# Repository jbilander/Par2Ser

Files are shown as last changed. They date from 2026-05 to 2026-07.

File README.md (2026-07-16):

# Amiga Par2Ser device

> 🚧 **Status: Proof of concept — working, not yet fast.** The link is
> verified end-to-end on real Rev 2A hardware in both directions: interactive
> terminal traffic and **kermit file transfers** both work (a 512 KB ROM image
> and a 906 KB binary have been transferred with essentially zero packet
> errors). Current throughput is roughly **3400 CPS transmit / 1400 CPS
> receive** (release build). That is not yet a win over the built-in serial
> port — a stock A500 runs kermit at 38400 baud (~3800 CPS) via `8n1.device` —
> so **throughput optimization is the active work**; the whole point of going
> through the parallel port is to beat that comfortably. There are no tagged
> releases until it does, so **build at your own risk** and expect the design
> to still change. PRs and issues welcome.

***
Rev. 2A <br />
<a href="images/Par2Ser_rev2A_pic1.png">
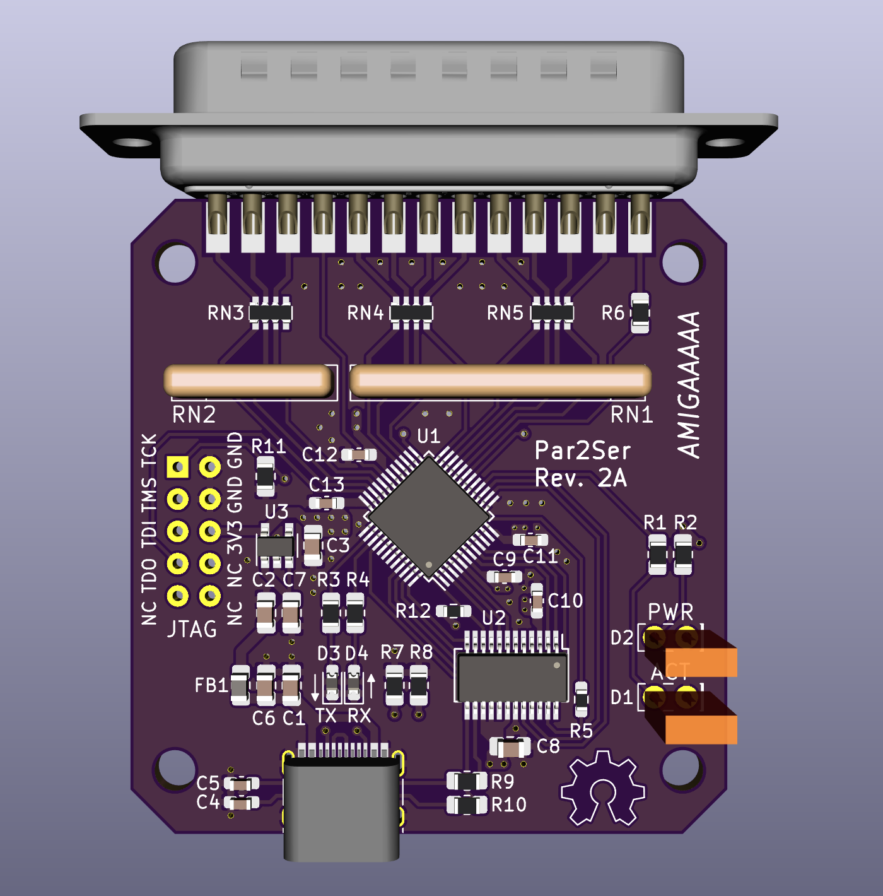
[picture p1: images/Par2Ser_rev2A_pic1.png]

</a>

***

A `serial.device`-compatible Amiga driver that bridges the parallel port to a
USB FIFO (FT240X) via Niklas Ekström's 2E parallel-adapter protocol, so unmodified
comms programs (c-kermit, NComm, …) can `set line par2ser.device`.

The hardware side is a small board built around a Lattice **LC4064V-75TN48C**
CPLD that speaks the 2E protocol to the Amiga and presents the bytes to an
**FT240X** USB FIFO. The PC sees a standard USB serial port (VCP).

## Repository layout

- **`amiga/`** — `par2ser.device` driver source (m68k, Bartman gcc).
- **`cpld/`** — Verilog firmware for the Lattice LC4064V CPLD.
  - `rtl/` — design sources (`par2ser_top.v`, `par2ser_fsm.v`).
  - `sim/` — Icarus Verilog smoke testbench.
  - `isplever/` — Lattice ispLEVER Classic 2.1 project files and pin
    constraints (`Par2Ser.lci`).
- **`KiCad/`** — KiCad 5.1 schematic and PCB sources (Rev 2A).
- **`FT_PROG/`** — FT_PROG template (`Par2Ser.xml`) capturing the
  FT240X MTP settings the bridge needs (VCP enabled, CBUS5 → CLK12MHz,
  product description). Open it in FT_PROG and apply to a fresh
  board to skip the manual click-through.
- **`images/`** — board photos and screenshots used in this README.
- **`Par2Ser_rev2a_schematic.pdf`** — exported schematic for quick
  reference without opening KiCad.

## Hardware overview (Rev 2A)

- **Lattice LC4064V-75TN48C** CPLD (48-pin TQFP, 64 macrocells, -75 speed)
- **FTDI FT240X** USB-to-parallel-FIFO (SSOP-24), USB-C connector
- **8-bit bidirectional buffer** between the Amiga DB-25 and the CPLD
- **JTAG header** for programming the CPLD via ispVM System with a
  cheap FT4232H-mini-module-based cable

The driver is built in the style of [SimpleDevice](https://github.com/jbilander/SimpleDevice)
for the Bartman `m68k-amiga-elf` (gcc 15.1) toolchain. The serial machinery
(receive ring buffer, `CMD_READ` satisfied from buffer, `SDCMD_QUERY` count
from a software counter) is ported from Iain Barclay's `8n1.device` 43.5.

It targets **Kickstart 1.3** (and up): the sources include `<ks13_compat.h>`,
which uses `#pragma GCC poison` to turn any accidental call to a KS 2.0+
library function into a compile error, so the driver stays loadable on an
unexpanded A500/A2000.

## Bill of Materials (Rev 2A)

Sourcing notes: most actives and precision passives are from
[Mouser](https://www.mouser.com/), the connectors and decorative
LEDs are inexpensive enough to come from AliExpress sellers (linked
examples below — any equivalent footprint works). Generic 0805/0603
passives can be substituted with any reputable manufacturer's part
matching the value, package, and dielectric/tolerance noted.

| Ref | Qty | Value / Part | Description | Package | Source | Notes |
|---|-----|---|---|---|---|---|
| **U1** | 1 | LC4064V-75TN48C | Lattice ispMACH 4000V CPLD | 48-TQFP | [Mouser 842-LC4064V75TN48C](https://www.mouser.com/ProductDetail/842-LC4064V75TN48C) | 64 macrocells, -75 speed grade |
| **U2** | 1 | FT240XS-R | FTDI USB-to-parallel FIFO | SSOP-24 | [Mouser 895-FT240XS-R](https://www.mouser.com/ProductDetail/895-FT240XS-R) | USB 2.0 Full Speed; VCP driver |
| **U3** | 1 | TLV75533PDBVR | TI 3.3 V LDO regulator, 500 mA | SOT-23-5 | [Mouser 595-TLV75533PDBVR](https://www.mouser.com/ProductDetail/595-TLV75533PDBVR) | Fixed 3.3 V output |
| **J1** | 1 | DB25 Male | Right-angle PCB DB-25 (M) | Solder cups | [AliExpress example](https://www.aliexpress.com/item/1005006354086316.html) | Amiga parallel port |
| **J2** | 1 | USB-C 2.0 (TYPE-C-02) | 16-pin USB-C, USB 2.0 only (no SuperSpeed) | SMD + THM tabs | [AliExpress example](https://www.aliexpress.com/item/1005005371954812.html) | Common "TYPE-C-02" footprint |
| **J3** | 1 | 2×5 pin header | 2.54 mm pitch, 10-pin (2×5) | Through-hole | [AliExpress example](https://www.aliexpress.com/item/1005001493183557.html) | Optional — can press-fit ribbon during programming |
| **FB1** | 1 | 600 Ω @ 100 MHz | Ferrite bead | 0805 | [Mouser 875-HZ0805E601R-10](https://www.mouser.com/ProductDetail/875-HZ0805E601R-10) | USB VBUS filter |
| **D1** | 1 | Yellow LED | Activity LED (optional) | 2×5×7 mm TH | [AliExpress example](https://www.aliexpress.com/item/1005006220921860.html) | Lit when transaction in progress |
| **D2** | 1 | Green LED | Power LED (optional) | 2×5×7 mm TH | [AliExpress example](https://www.aliexpress.com/item/1005006220921860.html) | 3.3 V rail indicator |
| **D3** | 1 | Red LED | TX LED | 0603 SMD | [AliExpress example](https://www.aliexpress.com/item/1005005975741298.html) | Amiga → PC byte flow |
| **D4** | 1 | Red LED | RX LED | 0603 SMD | [AliExpress example](https://www.aliexpress.com/item/1005005975741298.html) | PC → Amiga byte flow |
| **RN1** | 1 | 8×10 kΩ bussed (A09-103JP) | 9-pin SIP resistor network | SIP-9 | [AliExpress example](https://www.aliexpress.com/item/1005006954621214.html) | Amiga D0..D7 pull-ups, one common |
| **RN2** | 1 | 4×10 kΩ bussed (A05-103JP) | 5-pin SIP resistor network | SIP-5 | [AliExpress example](https://www.aliexpress.com/item/1005006954621214.html) | Additional Amiga-side pull-ups |
| **RN3, RN4, RN5** | 3 | 4×330 Ω isolated | 8-pin SMD isolated resistor array | 1206-8 | [Mouser 652-CAY16-3300F4LF](https://www.mouser.com/ProductDetail/652-CAY16-3300F4LF) | Series limiters on signal lines |
| **R1, R3, R4** | 3 | 1 kΩ | LED current limiter / signal | 0805 | [Mouser 652-CR0805FX-1001ELF](https://www.mouser.com/ProductDetail/652-CR0805FX-1001ELF) | |
| **R2** | 1 | 10 kΩ | Series for D2 power LED (high R = low brightness) | 0805 | [Mouser 652-CR0805FX-1002ELF](https://www.mouser.com/ProductDetail/652-CR0805FX-1002ELF) | Matches green power-LED forward voltage |
| **R5** | 1 | 33 Ω | CLKOUT line damping resistor | 0603 | [Mouser 652-CR0603FX-33R0ELF](https://www.mouser.com/ProductDetail/652-CR0603FX-33R0ELF) | Common practice for clock lines, not per FT240X datasheet  |
| **R6** | 0 | 330 Ω (**DNP**) | Series on /STROBE — not populated | 0805 | [Mouser 652-CR0805FX-3300ELF](https://www.mouser.com/ProductDetail/652-CR0805FX-3300ELF) | **Do Not Place** — populate only if /STROBE used in fw |
| **R7, R8** | 2 | 5.1 kΩ | USB-C CC1/CC2 pull-downs | 0805 | [Mouser 652-CR0805FX-5101ELF](https://www.mouser.com/ProductDetail/652-CR0805FX-5101ELF) | Identifies device as USB 2.0 (sink) |
| **R9, R10** | 2 | 27 Ω | USB D+/D− series | 0805 | [Mouser 652-CR0805FX-27R0ELF](https://www.mouser.com/ProductDetail/652-CR0805FX-27R0ELF) | Per USB 2.0 Full Speed spec |
| **R11** | 1 | 4.7 kΩ | Pull-down for TCK (JTAG) | 0805 | [Mouser 652-CR0805FX-4701ELF](https://www.mouser.com/ProductDetail/652-CR0805FX-4701ELF) | Standard JTAG practice |
| **R12** | 1 | 10 kΩ | Pull-up for SIWU# | 0603 | [Mouser 652-CR0603-JW-103ELF](https://www.mouser.com/ProductDetail/652-CR0603-JW-103ELF) | Keeps SIWU# deasserted when CPLD pin 44 is high-Z |
| **C1, C2** | 2 | 4.7 µF, 10 V, X7R | VBUS bulk / LDO input | 0805 | [Mouser 81-GRM21BR71A475KE1K](https://www.mouser.com/ProductDetail/81-GRM21BR71A475KE1K) | Murata GRM21 X7R, 10 V |
| **C3** | 1 | 1 µF, X7R | LDO output filter | 0805 | | Per TLV75533 datasheet |
| **C4, C5** | 2 | 47 pF, C0G/NP0 | USB D+/D− noise filter | 0603 | [Mouser 791-0603N470G160CT](https://www.mouser.com/ProductDetail/791-0603N470G160CT) | Tight tolerance important |
| **C6, C7, C8** | 3 | 0.1 µF, X7R | Decoupling (0805 spots) | 0805 | | |
| **C9 – C13** | 5 | 0.1 µF, X7R | Decoupling (0603 spots) | 0603 | | One per VCC pin |

**Distinct line items: 27** &nbsp;·&nbsp; **Components to populate: 37** (38 if /STROBE is wired up in a future firmware — see R6)

### Mounting and additional hardware

- The **LC4064V** is JTAG-programmable in-circuit — no socket needed.
- The **JTAG header (J3)** uses the standard Lattice 2×5 pinout —
  check `cpld/README.md` for the exact pinout and the recommended
  FT4232H-Mini-Module-based cable. The header doesn't have to be
  soldered down; you can press-and-hold the 2×5 ribbon cable
  against the pads during programming.

### 3D-printable case

A 3D-printable two-part case is provided in the `3D/` folder. It is
adapted from the former **SDBox-v2** case, slimmed down and made more
proportional — the Rev 2A design no longer has to house a bulky
Arduino Nano v3, so the enclosure is significantly thinner. The DB-25
exits one end and the USB-C port the other, and the top lid has two
holes for the panel LEDs: one for the **Power LED (green)** and one for
the **Activity LED (yellow)**.

| File | Description |
|---|---|
| `3D/Par2Ser.scdoc` | SpaceClaim source file for the case |
| `3D/Par2Ser.stp` | STEP export (top + bottom) for use in other CAD tools |
| `3D/Par2Ser_top.stl` | Top lid, ready to slice and print |
| `3D/Par2Ser_bottom.stl` | Bottom shell, ready to slice and print |
| `3D/Par2Ser_text.skp` | SketchUp source for the embossed "Par2Ser" lid text |

<table>
  <tr>
    <td align="center">
      <a href="images/Par2Ser_case_pic3.png">
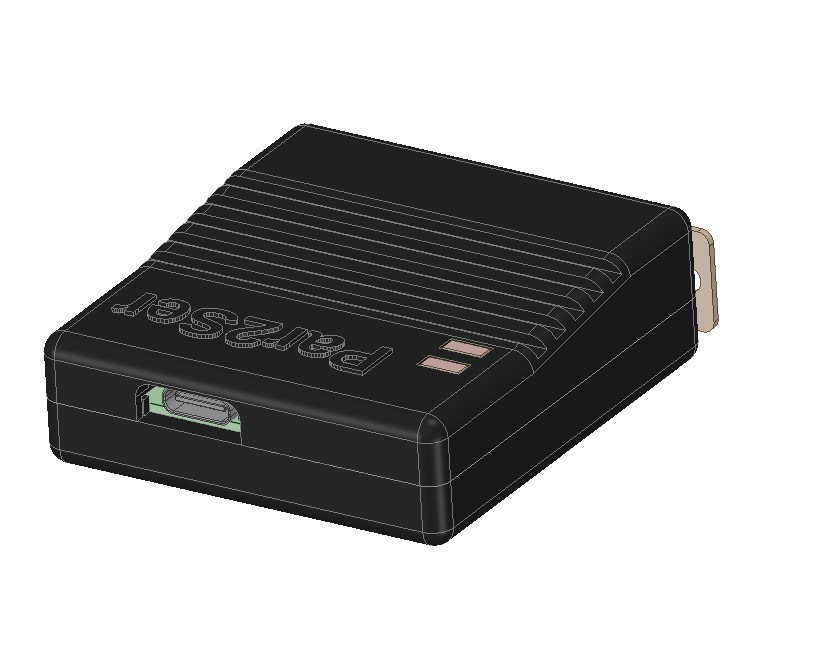
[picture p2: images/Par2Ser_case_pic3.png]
        
      </a><br />
      <sub>USB-C end, with the two LED holes in the top lid</sub>
    </td>
    <td align="center">
      <a href="images/Par2Ser_case_pic1.png">
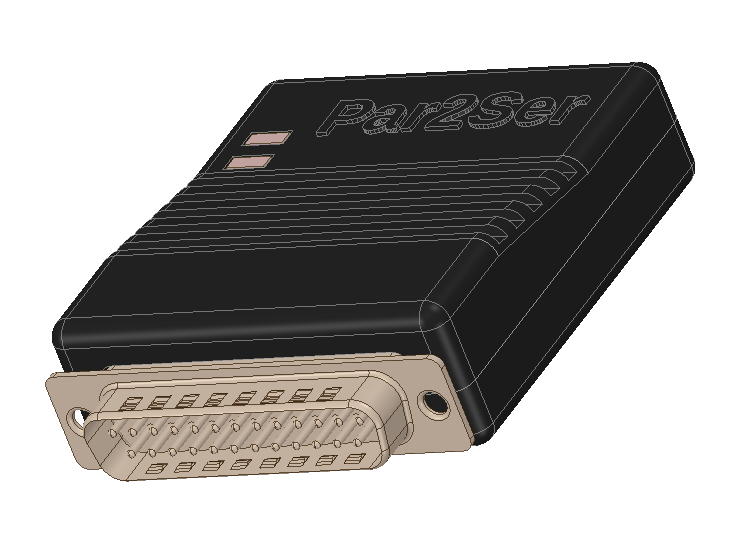
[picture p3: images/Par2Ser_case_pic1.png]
        
      </a><br />
      <sub>DB-25 end</sub>
    </td>
  </tr>
  <tr>
    <td align="center">
      <a href="images/Par2Ser_case_pic4.png">
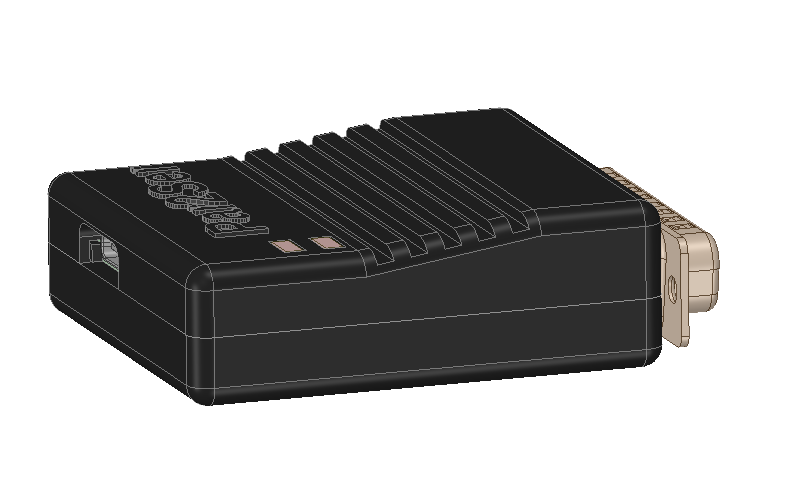
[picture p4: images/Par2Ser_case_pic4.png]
        
      </a><br />
      <sub>Side profile showing the slimmer enclosure</sub>
    </td>
    <td align="center">
      <a href="images/Par2Ser_case_pic2.png">
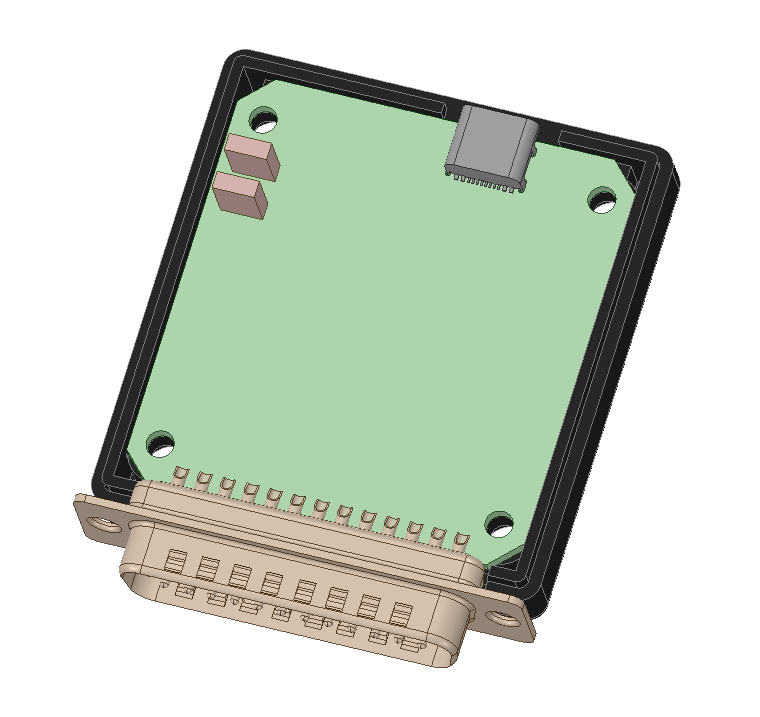
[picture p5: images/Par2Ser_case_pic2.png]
        
      </a><br />
      <sub>PCB fitted into the bottom shell</sub>
    </td>
  </tr>
</table>

The renders above are from the CAD program. The case was printed on a
Creality Ender-3 Pro in white PLA. The build photos below show the
assembly steps and the finished unit fitted to an Amiga 500.

#### Fitting the panel LEDs

The two indicator LEDs are soldered last. Fit the **PWR (green, Power)**
and **ACT (yellow, Activity)** LEDs into their positions, then check
from the top that each one protrudes ever so slightly through its hole
in the case lid. Once the height looks right, tack down a single leg,
snip the leads flush, and only then solder both joints properly. Doing
it in that order keeps the LEDs sitting at the correct height instead of
being pushed in or standing too proud.

<table>
  <tr>
    <td align="center">
      <a href="images/Par2Ser_soldering_PWR_and_ACT_LEDs.jpg">
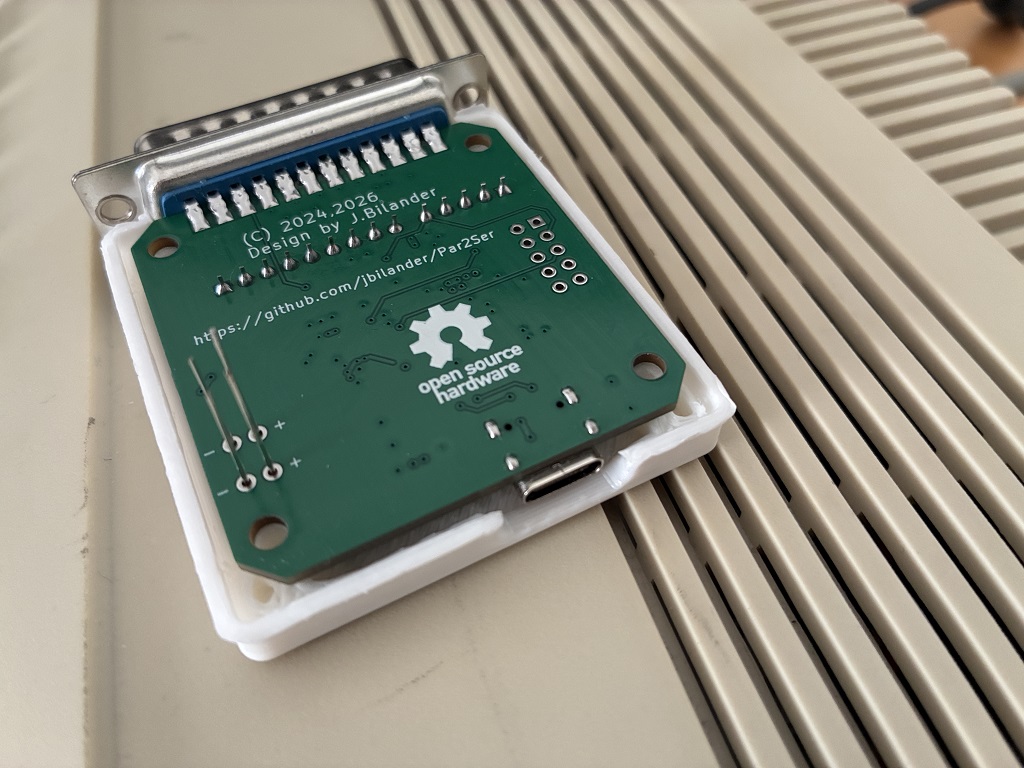
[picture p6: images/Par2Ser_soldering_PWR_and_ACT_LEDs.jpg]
        
      </a><br />
      <sub>Test-fitting the green PWR and yellow ACT LEDs before tacking them down</sub>
    </td>
    <td align="center">
      <a href="images/Par2Ser_soldering_completed.jpg">
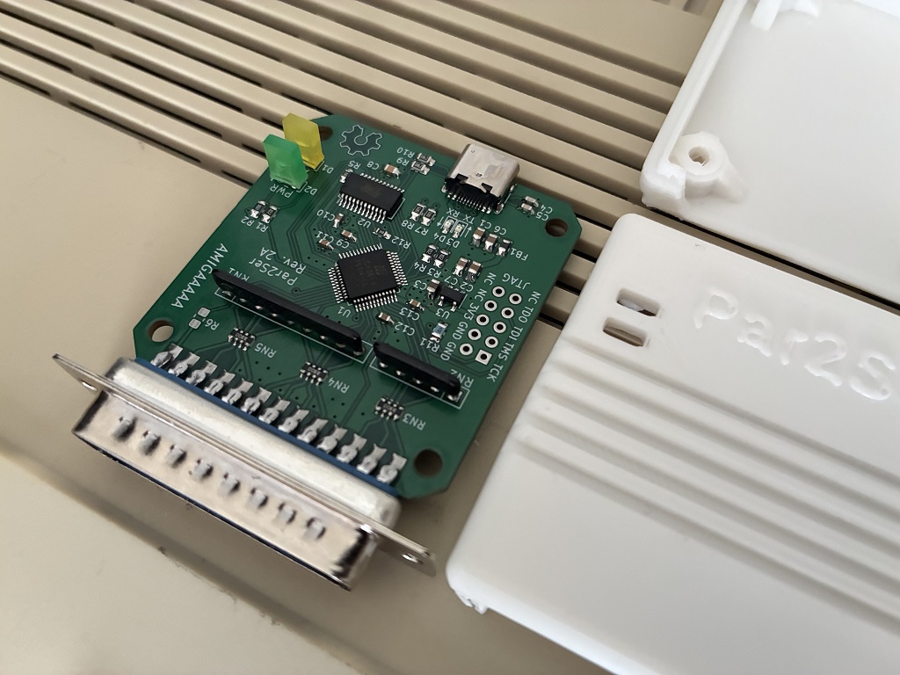
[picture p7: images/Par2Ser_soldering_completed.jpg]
        
      </a><br />
      <sub>Underside of the finished board seated in the bottom shell</sub>
    </td>
  </tr>
</table>

#### Finished unit

<table>
  <tr>
    <td align="center">
      <a href="images/Par2Ser_installed_in_case.jpg">
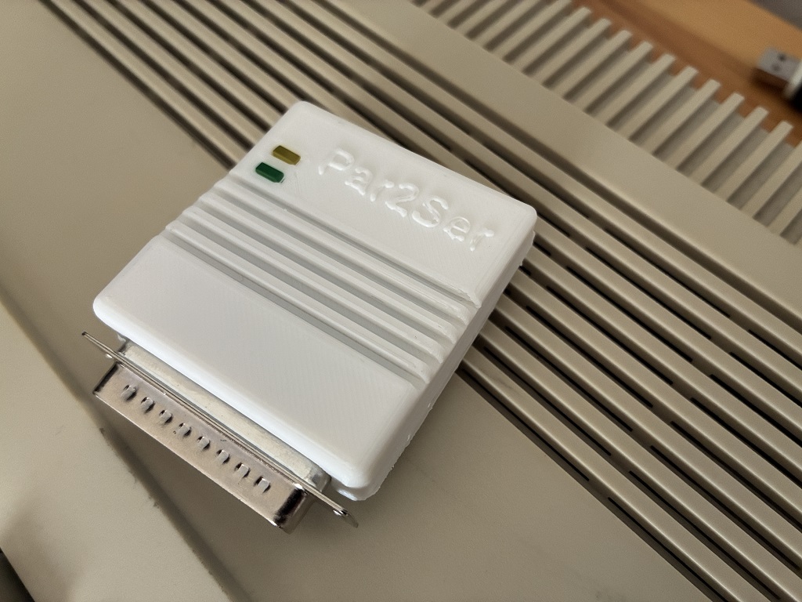
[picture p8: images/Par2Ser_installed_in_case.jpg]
        
      </a><br />
      <sub>Assembled case closed up, with the PWR/ACT LEDs visible through the lid</sub>
    </td>
    <td align="center">
      <a href="images/Par2Ser_installed_in_A500_and_connected_to_PC.jpg">
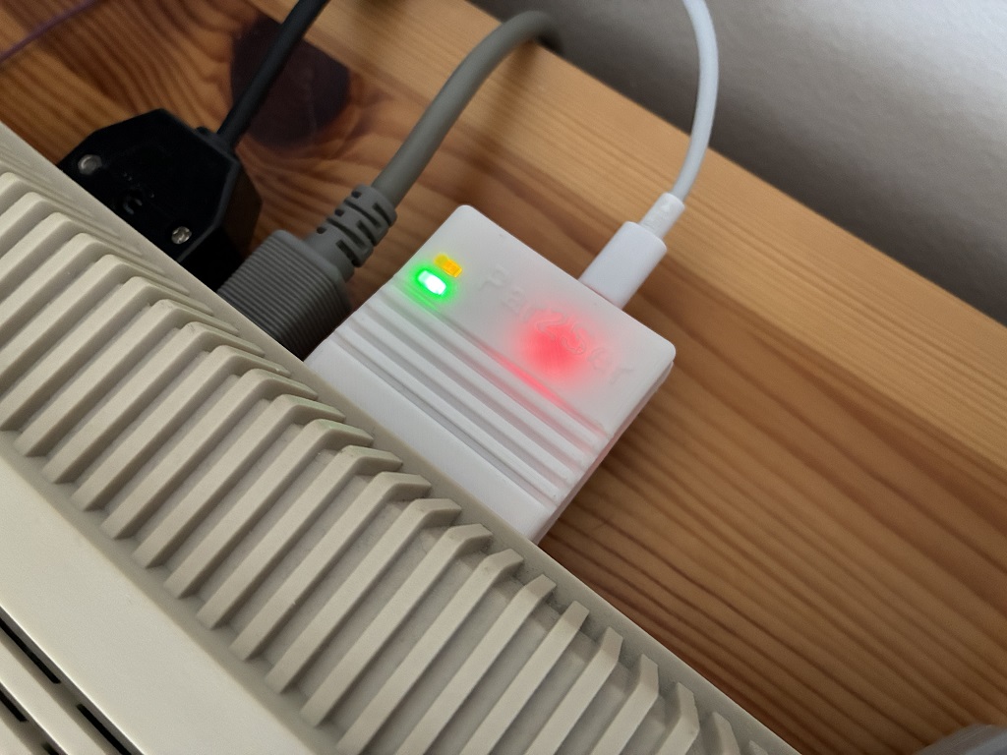
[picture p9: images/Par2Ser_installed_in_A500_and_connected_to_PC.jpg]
        
      </a><br />
      <sub>Plugged into the A500 parallel port and connected to a PC over USB-C</sub>
    </td>
  </tr>
</table>

In the powered-on photo the green **PWR** LED is lit, and the red glow
bleeding through the lid is the FT240XS **RX/TX** LEDs shining through
the white PLA — here the blink firmware has the **TX** LED on. This is
something of a happy accident: if you don't want the glow, print the
case in black or another dark material, or simply leave the RX/TX LEDs
unpopulated.

> **Note:** The USB-C cut-out in the current print is slightly too wide.
> It's a cosmetic issue only — the port works fine — and will be tidied
> up shortly so the opening sits more symmetrically around the connector.

## Files (amiga/)

- `par2ser.c` — device skeleton + serial command set + receive ring buffer
- `transport.h` / `transport.c` — byte-pipe to the adapter (**stubbed** for now)
- `debug.c` — `KPrintF` over `RawDoFmt`/`RawPutChar` (verbatim from SimpleDevice)
- `Makefile`

## Build (amiga/)

```sh
cd amiga
make debug      # build-debug/par2ser.device, with KPrintF tracing
make release    # build-release/par2ser.device, stripped
```

Adjust `INCDIRS` for your NDK path as in SimpleDevice.

## Programming the FT240X (one-time, before first use)

The CPLD needs a 12 MHz clock from the FT240X to operate. By default
the FT240X's CBUS5 pin is **not** configured as a clock output — you
have to set its function in the chip's internal MTP (one-time-programmable)
memory using FTDI's **FT_PROG** utility. While you're at it, you should
also tell the chip to advertise itself as a Virtual COM Port (VCP) so
that comms software on the host can open it as a regular serial port,
and you can optionally set a friendly USB product-description string.

These settings are all stored on the FT240X chip itself — they
persist across power cycles and across host machines.

### What you'll need

- FTDI **FT_PROG** (free download from <https://ftdichip.com/utilities/>;
  requires .NET Framework 4.0 or newer, which is included with
  Windows 8.1 and above)
- The Rev 2A board, powered via USB, on a Windows machine (FT_PROG
  is Windows-only; users on Linux/macOS can use a Windows VM, or
  the open-source `ftdi_eeprom` from libftdi as an alternative —
  see note at the end of this section)

### Install FT_PROG

Download FT_PROG from <https://ftdichip.com/utilities/> (current version
at time of writing: 3.12.75.692). Extract the ZIP, run the installer,
click through to **Finish**:

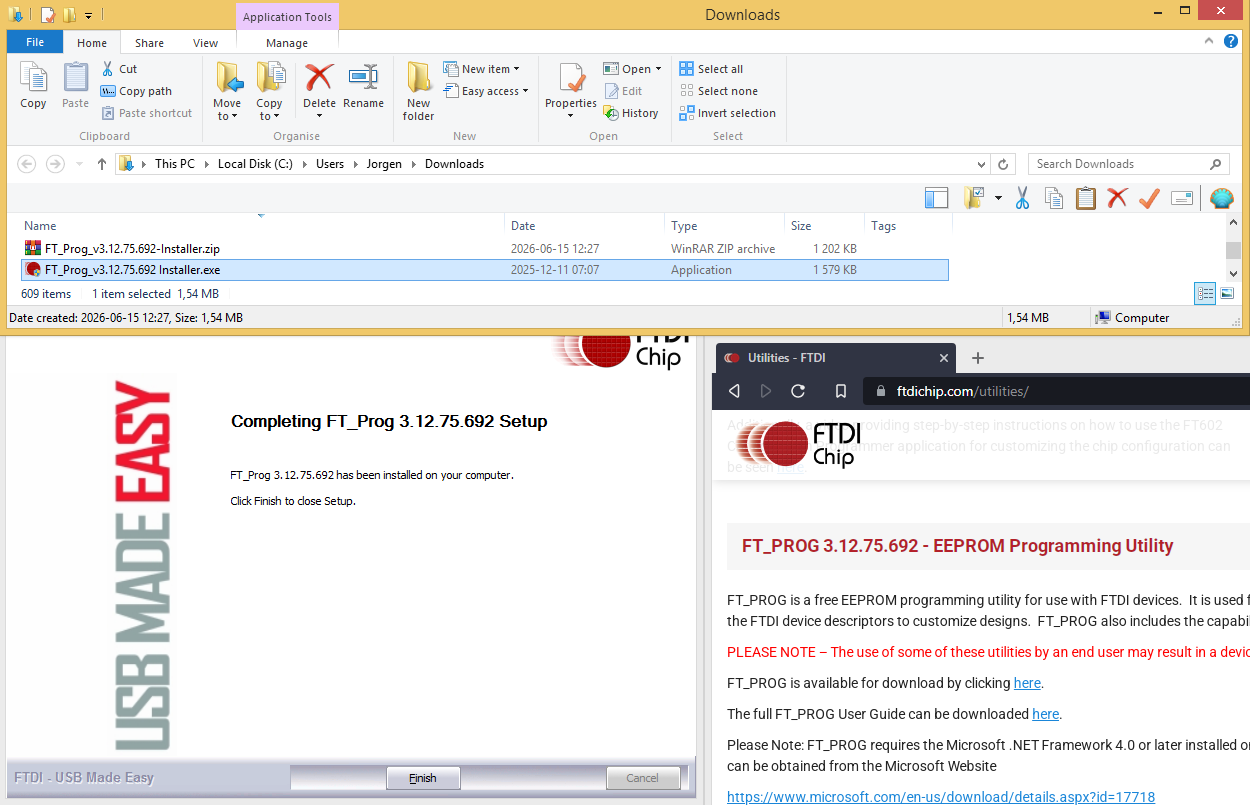
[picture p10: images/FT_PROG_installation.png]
FT_PROG installer


### Fast path: apply the supplied template

The `FT_PROG/Par2Ser.xml` file in this repo is a saved FT_PROG template
with all the settings the Par2Ser bridge needs (VCP enabled, CBUS5 →
CLK12MHz, CBUS6 → Keep_Awake#, Product Description → `Par2Ser USB Serial`).
The fast path is:

1. Plug the Rev 2A board into a Windows PC via USB-C. Windows will
   detect the FT240X and bind FTDI's bus-level driver, presenting
   the device as **"USB Serial Converter"** under
   *Universal Serial Bus controllers* in Device Manager.
2. Launch FT_PROG and **FILE → Open** the `FT_PROG/Par2Ser.xml`
   template — this loads the desired settings into FT_PROG's editor.
3. **DEVICES → Scan and Parse** (<kbd>Ctrl+P</kbd>) to bring the
   live chip's current settings under the same editor.
4. **DEVICES → Program** to apply the template values to the chip
   — confirm the success dialog appears.
5. Unplug and replug the board.

If you'd rather understand or customize each setting, walk through
the manual steps below instead.

### Manual walkthrough (step-by-step)

1. Plug the Rev 2A board into a Windows PC via USB-C. Windows will
   detect the FT240X and bind FTDI's bus-level driver, presenting
   the device as **"USB Serial Converter"** under
   *Universal Serial Bus controllers* in Device Manager. (Whether
   a COM port appears at this stage depends on the host's driver
   state — see "Driver behavior across operating systems" below.)

2. Launch FT_PROG. Click **DEVICES → Scan and Parse** (or
   <kbd>Ctrl+P</kbd>). The device tree on the left should populate
   with the FT240X, and the lower pane shows the EEPROM contents
   dump:

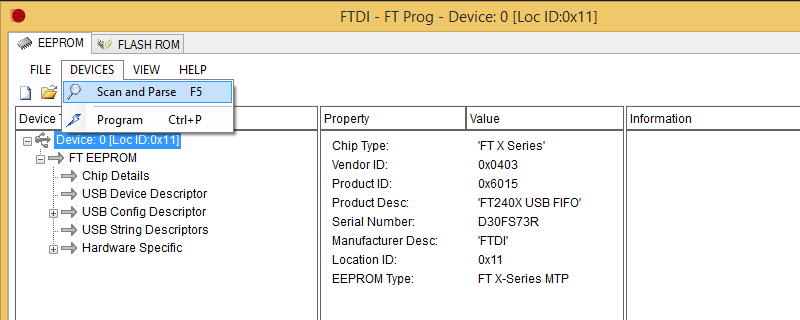
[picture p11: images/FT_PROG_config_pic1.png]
FT_PROG after Scan and Parse
   

3. Enable the **VCP driver mode**: in the device tree, expand
   **Hardware Specific → Port A → Driver** and select the
   **Virtual COM Port** radio button (it may be on "D2XX Direct"
   by default):

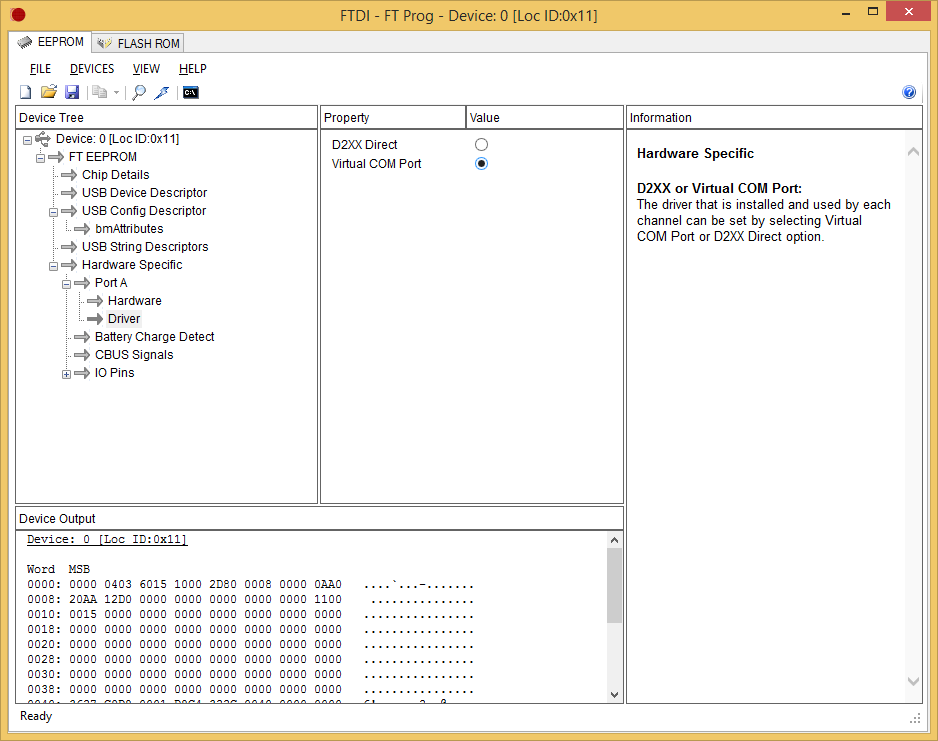
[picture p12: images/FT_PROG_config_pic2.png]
Virtual COM Port radio button selected
   

4. Configure the **CBUS5 clock output**: navigate to
   **Hardware Specific → CBUS Signals** and set the **C5** drop-down
   to **`CLK12MHz`**. The C6 drop-down can be left at its default
   (`Keep_Awake#`) — CBUS6 is wired to the CPLD but not used by the
   current firmware:

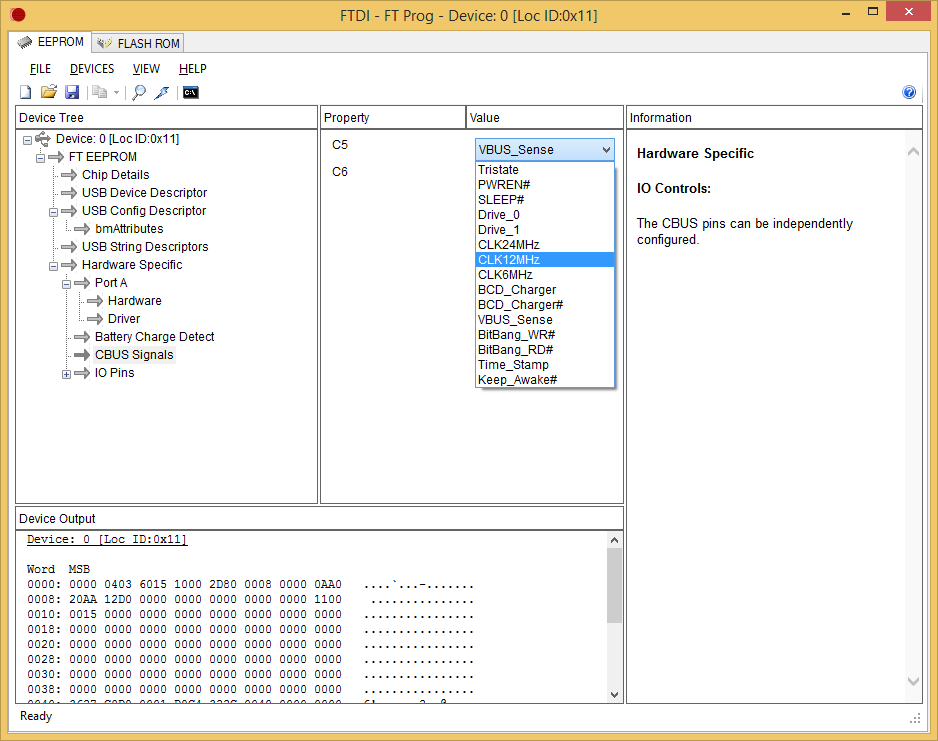
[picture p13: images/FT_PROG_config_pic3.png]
C5 set to CLK12MHz
   

5. (Optional) Update the **USB String Descriptors** to identify the
   device as a Par2Ser. Setting the *Product Description* to
   `Par2Ser USB Serial` makes it easier to find when several FTDI
   devices are plugged into the same host. The factory-assigned
   *Serial Number* is unique per chip and stable — useful when
   binding driver settings or `udev` rules per device:

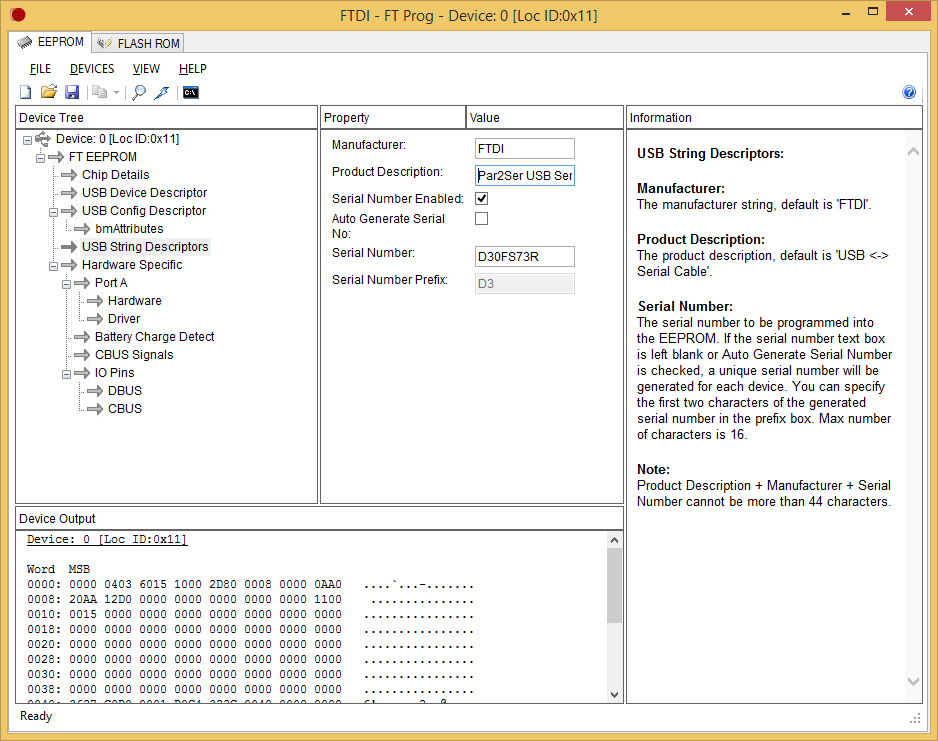
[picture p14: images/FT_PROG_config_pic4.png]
Product Description set to Par2Ser USB Serial
   

6. Click **DEVICES → Program** (the lightning-bolt icon). The
   *Program Devices* dialog shows the chip type, VID/PID, and the
   strings about to be written to MTP. Confirm the values look right
   and click **Program**:

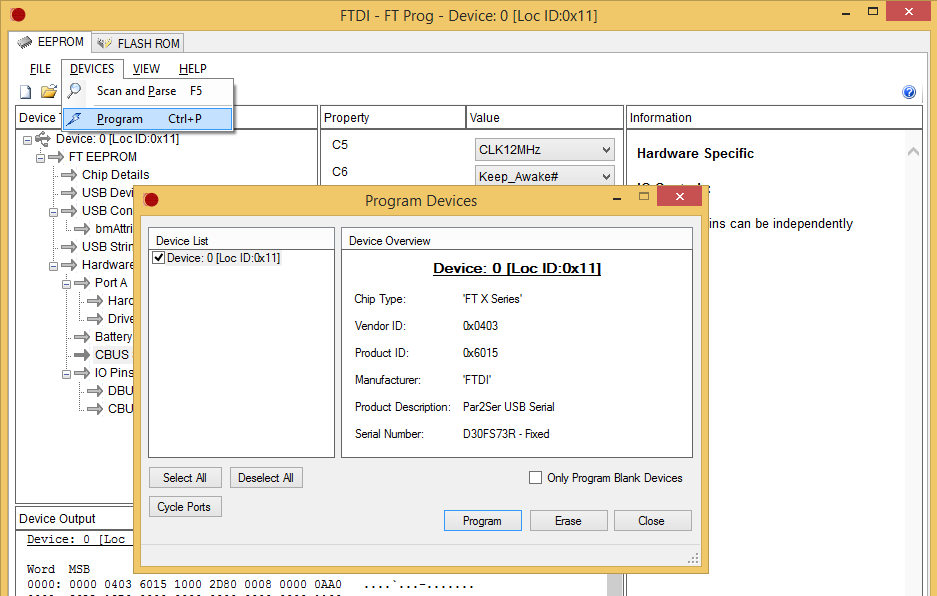
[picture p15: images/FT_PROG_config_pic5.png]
Program Devices dialog
   

   You should see **"Programming Successful"** at the bottom of the
   dialog when the write completes:

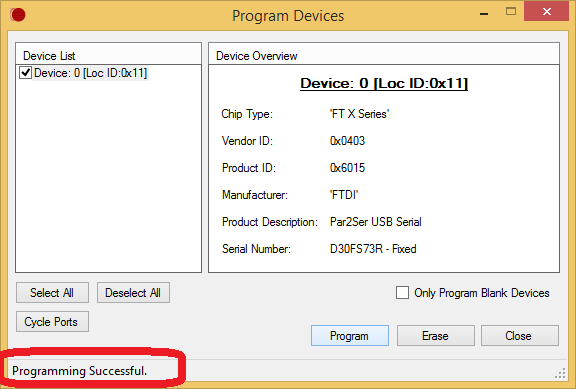
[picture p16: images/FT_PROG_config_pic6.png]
Programming Successful
   

7. Unplug and replug the board. Windows will re-enumerate the device.

### Verifying the configuration

After the FT_PROG round-trip, you can confirm the chip is configured
correctly with one or both of:

**A. Oscilloscope check of the 12 MHz clock.** With the board powered
via USB, probe the trace at R5 (the damping resistor on the CPLD's
clock input). You should see a clean ~12 MHz square wave near rail-to-rail
on a 3.3 V LVTTL swing:

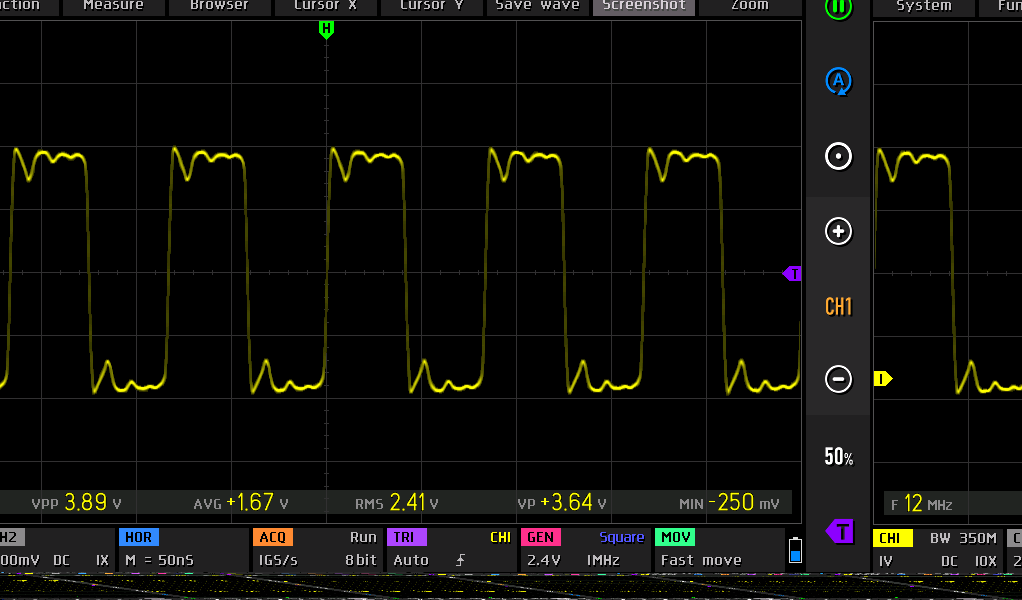
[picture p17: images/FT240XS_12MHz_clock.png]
12 MHz clock at R5


The small overshoot/ringing on the edges is the scope probe's ground-lead
inductance, not a problem with the signal — using a probe ground spring
close to the test point cleans it up. The signal is well within LVTTL
input tolerances at the CPLD's pin 43.

**B. COM-port enumeration check on the host.** The board should appear
as a serial port. The device name varies by OS — see below.

### Driver behavior across operating systems

The FT_PROG settings live on the chip; *whether* a given host then
makes them visible as a normal COM/tty port depends on what FTDI driver
support that host has. Tested behavior so far:

| Host | Result | Driver intervention needed |
|---|---|---|
| **macOS 10.15 Catalina** | `/dev/cu.usbserial-XXXXXXXX` on plug-in | None — Apple's built-in `AppleUSBFTDI` driver handles it |
| **Linux** (Pop!\_OS, Ubuntu, similar) | `/dev/ttyUSB0` on plug-in | None — the in-kernel `ftdi_sio` module binds automatically |
| **Windows 10/11** | `USB Serial Port (COMn)` under *Ports (COM & LPT)* | Typically none — Windows Update pushes the FTDI CDM (Combined Driver Model) package automatically |
| **Windows 8.1** | Depends on the machine's history (see below) | One-time CDM install on a fresh host |

The Windows 8.1 case is the only one with a footgun, and it's
machine-specific rather than OS-specific. On Windows 8.1, the **CDM
(Combined Driver Model)** package — which contains both the bus-level
driver (`USB Serial Converter`) *and* the VCP layer that creates the
COM port — is not bundled with the OS. It can be installed via
Windows Update, but isn't always pushed automatically.

In our testing on two Windows 8.1 SP2 machines:

- **Machine A**: had previously hosted other FTDI devices. When the
  Par2Ser board was first plugged in, Windows auto-installed both
  the USB Serial Converter and the VCP layer, and a COM port
  (`COM4`) appeared under *Ports (COM & LPT)* immediately. The
  "Installing Par2Ser USB Serial" progress dialog appeared
  automatically:

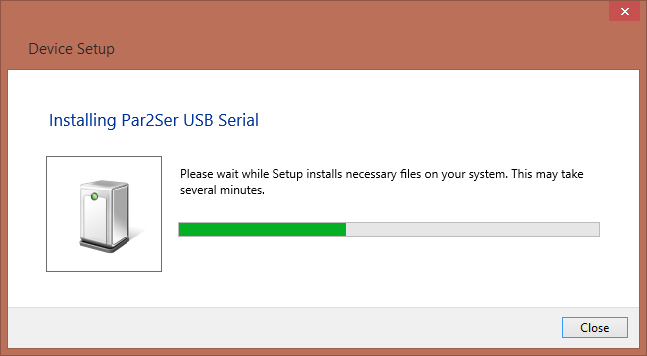
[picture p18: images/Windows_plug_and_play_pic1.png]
Windows automatic install dialog
  

  After the install, Device Manager's Events tab on the resulting
  `USB Serial Port (COMn)` entry shows the FTDI VCP driver service
  `FTSER2K` being registered and `ftdiport.inf` driving the COM-port
  instance — the proof that the VCP layer attached on top of the
  bus-level driver:

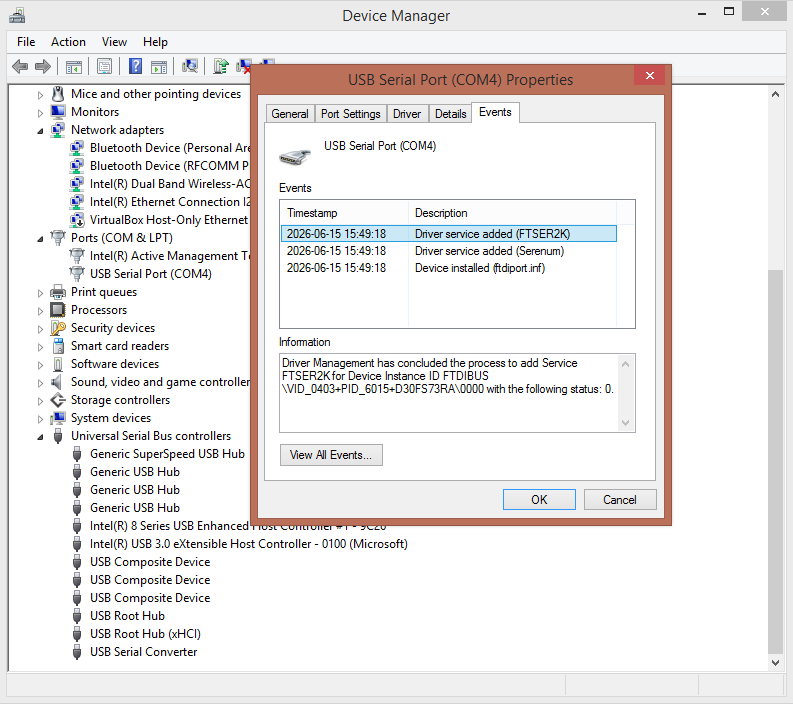
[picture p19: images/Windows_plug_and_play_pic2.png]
COM port Events tab showing FTSER2K registration
  

- **Machine B**: had not previously had an FTDI device on it.
  Plugging in the Par2Ser board only created the *USB Serial
  Converter* entry under *Universal Serial Bus controllers*; no COM
  port appeared. **The fix on this machine turned out to be very
  simple**: right-click *USB Serial Converter* in Device Manager,
  choose **Uninstall**, in the dialog that appears **leave the
  "Delete the driver software for this device" checkbox unchecked**,
  click OK, then unplug and replug the board. Windows re-enumerated
  the device, picked up the VCP driver this time, and `COM10`
  appeared under *Ports (COM & LPT)*. Total time: about 30 seconds.

  This "uninstall (keep files) then replug" trick works on a Win8.1
  machine that has the FTDI VCP driver files present on disk but
  somehow bound only the bus-level driver on the first plug-in.
  The driver files are kept; only the device-to-driver binding is
  cleared, so the next enumeration can re-pick the correct (full)
  driver stack.

**If you're on Windows 8.1 (or earlier) and no COM port appears**,
try the uninstall-without-deleting-files trick first — it's quick
and reversible. If that doesn't work (the VCP driver files truly
aren't present on the machine), install FTDI's CDM driver package
from <https://ftdichip.com/drivers/vcp-drivers/> — download the
*setup executable*, unplug the board, run the installer, replug.
After that the COM port will appear on every subsequent plug-in.
The MTP setting in the chip stays correct throughout; only the
host needs the right driver layer bound.

On Linux and macOS, no equivalent step is needed — the driver shipped
with the OS supports the FT240X out of the box.

### Linux/macOS alternative for the MTP programming (libftdi)

On non-Windows systems, the MTP programming (CBUS5 → CLK12MHz, VCP
enable, etc.) can be done with `ftdi_eeprom` from the `libftdi`
package — but it has not been tested by the author of this repo.
You'd need a small config file pointing at the FT240X (matched by
VID/PID `0403:6015`) and setting `cbus5=CLK12`. See the libftdi
documentation for the exact syntax.

The simplest path for now is to do the one-time FT_PROG step on any
available Windows machine. Once the FT240X's MTP is programmed, the
chip behaves identically on any host.

## Programming the CPLD via JTAG

The LC4064V is programmed in-circuit via the 2x5 JTAG header (J3)
using **ispVM System** (the legacy Lattice programming tool, bundled
with the free ispLEVER Classic install). For the JTAG cable, an
inexpensive **FT4232H Mini Module** works well as a generic FTDI
cable that ispVM recognizes as `USB2 / FTUSB-0` without needing any
EEPROM modification.

### Wiring (FT4232H Mini Module ↔ Par2Ser J3)

The FT4232H's channel A MPSSE pins map to JTAG signals as follows:

| FT4232H Mini Module | JTAG signal | Par2Ser J3 pin |
|---|---|---|
| **AD0** (ADBUS0) | TCK | pin 1 (TCK) |
| **AD1** (ADBUS1) | TDI | pin 5 (TDI) |
| **AD2** (ADBUS2) | TDO | pin 7 (TDO) |
| **AD3** (ADBUS3) | TMS | pin 3 (TMS) |
| any GND on module | GND | pin 2 or 4 |

Do NOT connect the FT4232H's 3.3 V or 5 V output to J3 — the
Par2Ser self-powers from USB-C and J3 pin 6 (3V3) is an output
from the board, not a power input.

The J3 header doesn't have to be soldered down — you can press
the 2x5 ribbon connector (or individual jumper wires) against the
through-hole pads with gentle hand-held force during programming.

*Note: RN2, the 10 kΩ pull-up network for TMS, can be left
unpopulated and JTAG will still work. The FT4232H actively drives
TMS during programming, and the LC4064V has a weak internal
pull-up on TMS per IEEE 1149.1. RN2 should still be populated
before final use for noise immunity when the JTAG cable is
disconnected.*

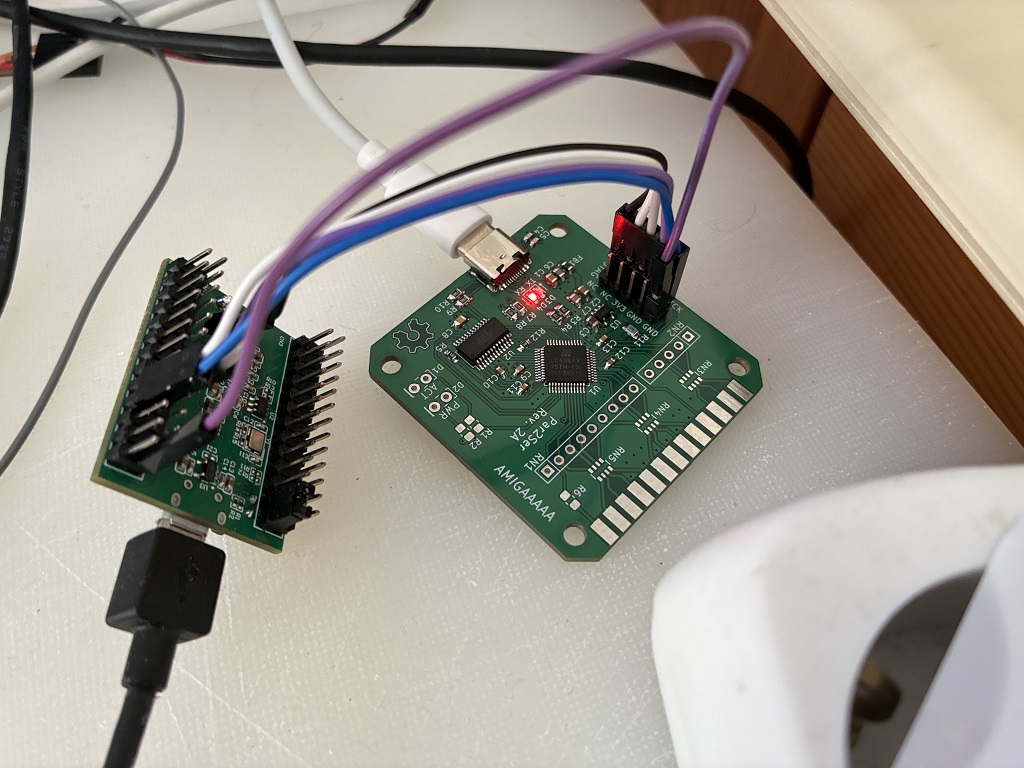
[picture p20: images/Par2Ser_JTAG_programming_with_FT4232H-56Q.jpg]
Par2Ser JTAG programming with FT4232H Mini Module


### Driver setup (Windows)

For ispVM to talk to the JTAG cable, **channel A (Interface 0) of
the FT4232H must be bound to FTDI's D2XX driver** (not
libusb-win32, WinUSB, or libusbK). The other three interfaces
(B/C/D) are not used by ispVM and can stay bound to whatever
driver they had previously.

After plugging in the Mini Module, open Device Manager and locate
the four "Quad RS232-HS" entries (Interface 0/1/2/3). If
Interface 0 is bound to the wrong driver — for example, listed
under *libusb-win32 device* (a typical leftover from a previous
OpenOCD session) rather than under *Universal Serial Bus
controllers* — rebind it:

1. Right-click **Quad RS232-HS (Interface 0)** → **Update Driver
   Software** → **Browse my computer for driver software** →
   **Let me pick from a list of devices on my computer**.
2. Select **USB Serial Converter A** (FTDI's D2XX driver, version
   2.12.36.4 or newer).
3. Click Next. Windows will rebind Interface 0 to the D2XX driver
   without affecting Interfaces 1–3.
4. **Restart ispLEVER/ispVM** — without this, the running ispVM
   process still has the old driver state cached and will not see
   the cable.

After the rebind, Device Manager should show one entry as
`USB Serial Converter A` under *Universal Serial Bus controllers*
(Interface 0, the one ispVM will use), and the other three
interfaces (1/2/3) wherever they were before — that's fine, they're
not used for JTAG.

### Programming procedure

1. **Power the Par2Ser from a USB charger**, not from the same PC
   running ispVM. This is important: if the Par2Ser is plugged into
   the same Windows host that is running ispVM, both FTDI devices
   (the Par2Ser's FT240X and the FT4232H Mini Module) appear as
   "USB Serial Converter" entries, and ispVM can grab the wrong one.
   Powering Par2Ser from a separate USB charger keeps it powered
   while leaving only the FT4232H Mini Module visible to ispVM.

2. **Connect the JTAG cable** per the wiring table above, with the
   FT4232H Mini Module plugged into the Windows PC.

3. **Launch ispVM System** (Start Menu → Lattice Semiconductor →
   ispVM System).

4. **Scan Board** (toolbar button) — should detect the LC4064V and
   show it as `LC4064V(B)-32IO` in the chain. (The `(B)-32IO` is
   ispVM's internal name for the 64-macrocell, 32-IO variant — your
   physical chip is the TQFP48 package of that die.)

5. **Double-click the device row** in the chain → set **Data File**
   to the `.jed` file generated by the ispLEVER fitter → set
   **Operation** to *Erase, Program, Verify*.

6. **(Important) Slow down TCK for flywire JTAG.** Open
   **Project → Project Settings → Advanced** and set
   **TCK Low Pulse Width Delay** to **3** or higher. The default
   15 MHz TCK is too fast for the typical flywire connection from
   the FT4232H to J3 — the verify step will fail with all-zeros
   readback on TDO. Stretching the TCK low-pulse by 3× makes
   programming reliable. Note that this setting is **per-project
   in ispVM**, so it has to be set again when switching projects.

7. **Click GO** (green arrow). Programming should complete in 3–10
   seconds with "Operation: Successful" and a green PASS in the
   Status column.

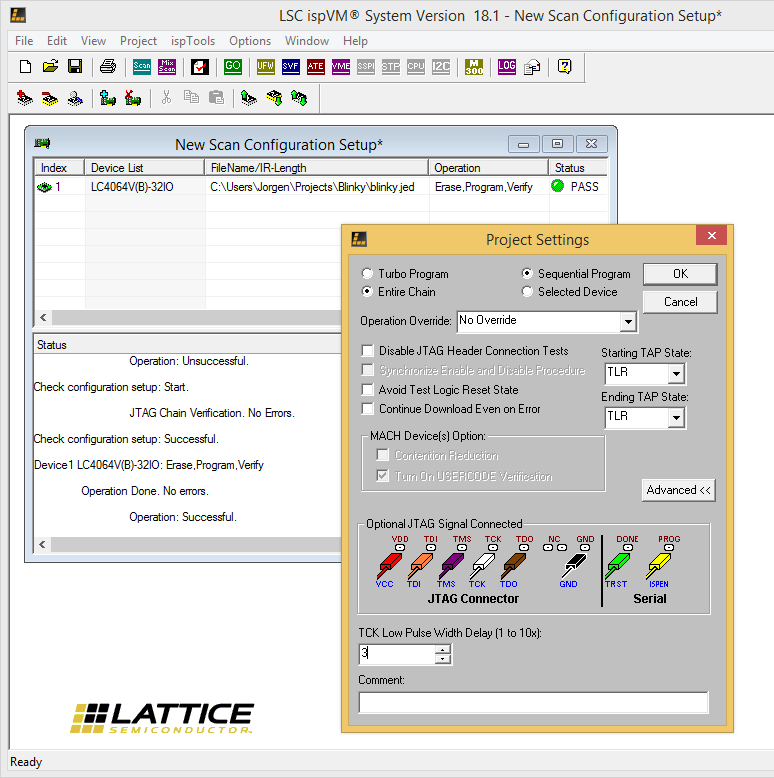
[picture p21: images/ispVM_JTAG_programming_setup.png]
ispVM JTAG programming setup with TCK Low Pulse Width Delay = 3


If the TCK Low Pulse Width Delay setting is left at the default
(1) and Debug mode is off, you'll see a `Failed in Function
VERIFY_USERCODE` error in the log, with received TDO reading all
zeros where the expected pattern was the programmed bitstream.
That's the signature of marginal TCK timing on flywire JTAG;
increasing the TCK Low Pulse Width Delay is the fix. (Enabling
Debug mode also happens to make programming work — the per-
transaction logging on the PC side adds enough pacing between
JTAG operations to mask the signal-integrity issue — but that's
an incidental workaround. The proper fix is the TCK delay
setting.)

## Milestone 1 — does kermit accept it? (no hardware needed) ✅

This milestone is **done**. It validates the driver in WinUAE without
any hardware:

1. `make debug` in `amiga/`, copy `build-debug/par2ser.device` to `DEVS:`
   in WinUAE.
2. Open a serial debug console (the same `RawPutChar` path SimpleDevice
   uses).
3. In kermit: `set line par2ser.device`. The trace shows `do_open()`,
   then the commands kermit issues (`SDCMD_SETPARAMS`, `SDCMD_QUERY`, …)
   with their parameters and the status word we return.

In this milestone `transport_write()` discards bytes (reports them sent)
and no RX data ever arrives, so a `CMD_READ` will stay pending — expected
with no hardware. The goal is purely to confirm acceptance and observe
the negotiation, especially the carrier check.

## Carrier / `/CD` handling

kermit checks carrier-detect before it will use the line. We have no real
CIA serial lines on the parallel port, so `SDCMD_QUERY` **synthesizes**
the status word. `serial.device` returns the raw (active-low) CIA-B
control lines, i.e. `0` = signal asserted, so the default
`ST_CARRIER_PRESENT = 0` reports CD/CTS/DSR all asserted.

The full word is `KPrintF`'d in `sdcmd_Query`, so if kermit reports
**NO CARRIER**, flip the polarity in `par2ser.c`:
```c
#define ST_CARRIER_PRESENT  ST_CD   /* try this if 0 doesn't satisfy kermit */
```
and compare the logged status against what kermit expects.

## Milestone 2 — real adapter ✅ (bidirectional, file transfers working)

### Transmit — working on hardware ✅

The Amiga → PC direction is verified on a real Rev 2A board: typing in
c-kermit (`cki196`) after `set line par2ser.device` / `connect` produces the
characters in a PC terminal on the FT240X's USB serial port, with the driver's
`KPrintF` trace confirming each `CMD_WRITE`.

Bring-up steps:

1. Build the CPLD firmware in ispLEVER Classic 2.1 — see `cpld/README.md`
   for details. The result is a `par2ser.jed` file.
2. Program the FT240X's CBUS5 to CLK12MHz output (see above).
3. Program the CPLD via ispVM System using a JTAG cable.
4. Build the driver with `make debug` in `amiga/` (the `Makefile` has
   `-DPAR2SER_HW` and the adapter objects enabled), copy
   `build-debug/par2ser.device` to `DEVS:`.

The low-level transport lives in `amiga/low-lib/` (`adapter.c`, `adapter.h`,
`adapter_low.s`). It is derived from Niklas Ekström's parallel-adapter
transport but renamed and reworked for Par2Ser: it is a byte-pipe, not SPI,
so the chip-select / card-present / speed-switch machinery was removed, the
fast-path assembly was ported from vasm to GNU-as syntax for the
`m68k-amiga-elf` toolchain, and the SD-card init was replaced with a plain
parallel-port grab. The WRITE1/READ1 command encoding and the SELECT/POUT/BUSY
handshake are unchanged and are decoded bit-for-bit by the CPLD FSM.

One hardware bug surfaced during TX bring-up and is fixed in the current RTL:
the FT240X write strobe was firing one clock before the CPLD drove the data
bus, so the chip latched a floating bus and bytes arrived as garbage. Driving
the data across the WR pulse (setup + hold around the falling edge) fixed it;
see `cpld/rtl/par2ser_fsm.v`.

### Receive — working on hardware ✅

The PC → Amiga direction also works: characters typed in a PC terminal appear
in c-kermit on the Amiga, and kermit file transfers complete in both
directions (`PAR2SER_RX_ENABLED` is 1 in `transport.h`).

One further bug had to be fixed before file transfers would run, and it was
pure protocol logic rather than hardware: `read_copy()` completed a `CMD_READ`
only once `io_Actual >= io_Length`, but kermit posts reads with a large buffer
(e.g. 9064 bytes) as a *maximum*, expecting back whatever has arrived. Every
packet's bytes landed in the ring correctly — zero overruns, exact counts —
and then the read sat pending forever waiting to fill the buffer, so kermit
timed out and retried every packet ("?Too many retries"). The Amiga
byte-stream convention is the opposite (console.device: *"if there is some
input, but not as much as can fill io_Length, the request will be satisfied
with the input currently available"*); completing the read as soon as any byte
has been delivered made transfers work immediately.

RX design: the adapter's ACK line (open-drain, DB25 pin 10) connects only to
**CIA-A /FLAG**, an interrupt-only CIA input — confirmed against the KiCad
netlist — so there is no readable doorbell level; the FLAG interrupt itself is
the data-available signal. The driver registers on the FLAG ICR bit via
**cia.resource** (`AddICRVector`, see `amiga/low-lib/cia_protos.h`) rather
than an `INTB_PORTS` server, so only genuine FLAG events are dispatched and
the shared ICR is owned correctly. The handler reads exactly **one byte per
FLAG**: the CPLD's IDLE-gated ACK re-asserts after each READ1 completes if
the FIFO still holds data, producing a fresh /FLAG edge per remaining byte —
the drain is hardware-self-clocking, no loop in the interrupt. A one-shot
`transport_rx_prime()` at device-open regenerates the doorbell edge for any
data that arrived before the interrupt was enabled (the CIA latches edges,
not levels).

Getting RX to work surfaced and fixed several deep bugs, documented in the
commit history — most notably a **gcc calling-convention trap**: `asm("reg")`
parameter annotations are honored on function *definitions* but silently
ignored on *prototypes*, so cross-file calls into the adapter transfer
functions passed garbage in a0/d0 (every READ1 scribbled memory through a
junk pointer; TX had only appeared correct by register coincidence). The
adapter API now uses the plain C convention, with explicit register variables
+ inline `jsr` shims only at the true `adapter_low.s` asm boundary. On the
CPLD side, the READ handshake was reworked: never drive the Amiga bus before
its first POUT edge (eliminating microseconds of bus contention against the
CIA on every read), present one byte per edge and hold it across the CIA's
~1.4 µs read, and capture FT240X data while RD# is still low. 58/64
macrocells, timing met with 72 ns slack.

### Throughput — the active work 🚧

File transfers work; making them *fast* is what remains. Measured with
kermit on a real Rev 2A board, release builds:

| direction | CPS | notes |
| --- | --- | ----- |
| TX (Amiga `send`) | ~3400 | after cutting the per-byte delay |
| RX (Amiga `get`)  | ~1400 | one FLAG interrupt per byte |

Target: comfortably past 38400 baud equivalent (~3800 CPS), since that is what
`8n1.device` already achieves on the built-in serial port.

What has been done and what is left:

- **Never benchmark a DEBUG build.** `KPrintF` goes out the real serial port
  at 9600 baud *synchronously*, ~1 ms per character, from inside the driver
  (and the receive ISR). A debug build measured ~570 CPS **with thousands of
  kermit retransmissions** — the debug spew was slow enough to time kermit out
  mid-packet. The same code in a release build ran ~3× faster with zero
  errors. Always `make release` for anything timing-related.
- **Per-byte TX delay (done).** `adapter_write_slow()` inherited a ~45 µs
  busy-wait per byte from Niklas's SD-card timing (~32 µs/byte at 250 kHz
  SPI) — irrelevant to this hardware. Cutting it to ~5.6 µs
  (`TX_BYTE_DELAY`, a tunable in `low-lib/adapter.c`) took TX from ~1900 to
  ~3400 CPS with no increase in errors. The floor has not been found yet;
  the knob can still be swept toward zero.
- **RX per-byte interrupt overhead (next, and the bigger prize).** Receive
  takes a full CIA-A FLAG interrupt per byte: dispatch, handler, one READ1
  transaction, `service_reads`, `ReplyMsg` — all for one byte. That overhead,
  not the inter-byte delay, is the RX ceiling. The fix is burst-draining
  several bytes per interrupt, which needs a way to know when to stop — i.e.
  a CPLD status command exposing "FIFO not empty" (there is macrocell
  headroom now: 58/64).
- **Fast-path assembly (unused).** `adapter_low.s` is built and linked but
  never called — `current_speed` stays SLOW, so the C bit-bang path runs.
  The asm clocks bytes with no inter-byte delay at all. Note it masks
  interrupts internally, so it is task-context only as written and would need
  rework before the receive ISR could use it.
- **Block streaming (later).** The >64-byte WRITE2/READ2 commands are not
  implemented in the current LC4064V FSM (D7=1 routes to `S_DRAIN`), so every
  transfer is chunked at 64 bytes. A whole kermit packet as one framed block
  would cut per-transaction overhead considerably — this is where a larger
  CPLD or a bespoke, parallel-tailored protocol would earn its keep.

### Other known issues

- **TX LED never visibly lights**: `led_tx` follows `drive_ft_d`, which is
  high ~166 ns per byte — too short to see. The RX and activity LEDs blink
  only briefly for the same reason. A pulse-stretcher counter in the CPLD
  (~50 ms per event) would fix all three; there is macrocell headroom now.
- Non-ASCII characters (å/ä/ö) may display wrong on the PC — check the
  Windows console codepage (the link itself is 8-bit clean).

## Credits

- **Niklas Ekström** — the 2E par-to-spi protocol and the SDBox
  adapter that this project is derived from. See his
  [amiga-par-to-spi-adapter](https://github.com/niklasekstrom/amiga-par-to-spi-adapter).
- **Iain Barclay** — `8n1.device` 43.5, the serial machinery template.
- **Bartman** — the `m68k-amiga-elf` toolchain.

## License

Licensed under [Creative Commons Attribution-ShareAlike 4.0 International](https://creativecommons.org/licenses/by-sa/4.0/)
(CC-BY-SA 4.0). You're free to use, modify, and redistribute this work
(including commercially), provided you give appropriate credit and
distribute derivative works under the same license.

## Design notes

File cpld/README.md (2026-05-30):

# Par2Ser CPLD Verilog

Verilog implementation of the Par2Ser bridge for the Lattice
**LC4064V-75TN48C** (ispMACH 4000V, 48-pin TQFP, 64 macrocells, -75 speed
grade). Ports Niklas Ekström's 2E parallel-port protocol (from
[amiga-par-to-spi-adapter](https://github.com/niklasekstrom/amiga-par-to-spi-adapter))
into Verilog, bridged to an FT240X USB FIFO.

> ⚠️ **Untested on real hardware.** Verified in Icarus Verilog simulation
> (WRITE smoke test and READ-hold test pass) and in the ispLEVER fitter.
> No board has been built yet — bring-up may reveal issues that simulation
> didn't catch.

## Files

- **`rtl/par2ser_top.v`** — Top-level. Pin declarations, input
  synchronizers, edge detectors, tristate drivers (with reset-aware OE),
  and FSM instantiation. Drives the LED outputs and the FT240X SIWU#
  signal.
- **`rtl/par2ser_fsm.v`** — Transaction FSM, **one-hot encoded** for
  better product-term sharing on the LC4064V. Decodes the command byte,
  handles the READ and WRITE per-byte loops clocked by POUT, drives
  BUSY/ACK back to the Amiga, and generates RD#/WR strobes for the
  FT240X.
- **`sim/par2ser_tb.v`** — Icarus Verilog smoke testbench (WRITE1 path).
- **`isplever/Par2Ser.lci`** — ispLEVER Classic pin/IO-type constraints
  (tracked); `Par2Ser.lct` is the tool's working copy (not tracked).

## Current fit status

```
Device:       LC4064V-75TN48C  (-75 speed grade)
Macrocells:   62 of 64        (97% — 2 cells of headroom)
Registers:    48
Product terms: 118
Timing:       worst path 11.20 ns vs 83.33 ns budget @ 12 MHz
              -> 72 ns slack, runs comfortably at the clock target
```

## Architecture decisions worth knowing

**Clock source.** The CPLD is clocked at 12 MHz from FT240X CBUS5 (CLKOUT
function, configured in FT_PROG — see top-level README). POUT is NOT the
clock — it's a synchronized input with any-edge detection ("one POUT
transition = one byte advances"). This sidesteps the dual-edge problem of
using POUT as a literal clock.

**Reset.** Amiga `_IORESET` is sensed on CLK1/I (CPLD pin 18), buffered
to 3.3 V externally, synchronized inside the CPLD, and used to force all
driven outputs to high-Z plus snap the FSM to IDLE. This ensures the
CPLD releases the parallel bus during an Amiga reboot.

**FSM encoding.** One-hot, 9 states (IDLE, DECODE, WRITE_WAIT,
WRITE_LATCH, WRITE_FT, READ_FETCH, READ_PRESENT, DRAIN, CTRL). Each
`state == N` test becomes a single wire instead of a 4-bit AND tree.
On this CPLD that reduced product terms from ~195 (binary FSM) to ~118
(one-hot), which is what enables all three activity LEDs to fit. Each
state bit has both an entry term and an explicit hold term
`state[N] & ~exit_condition` — without those, waiting states would clear
themselves after one cycle and the FSM would die.

**Tristate.** All bus tristates are done in per-pin logic with a reset
gate on each OE — not via the hardware GOE0/GOE1 nets. The two
dual-function pins (pin 41 = D14/GOE1, pin 44 = A0/GOE0) are otherwise
used as plain I/O: pin 44 is the SIWU# output to the FT240X; pin 41 is
unused and available.

**RX-ready interrupt.** The Amiga driver expects an interrupt when a
byte arrives from the PC. We drive `amiga_ack_n` (open-drain to
CIA-A FLAG) low whenever the FT240X has data waiting (RXF# low) AND
we're in IDLE. The H->L edge triggers /FLAG and the driver's
`INTB_PORTS` handler reads the byte.

**SIWU# (FT240X Send Immediate).** The Amiga driver can request an
FT240X TX buffer flush by issuing a control command (D7=1, D6=1 in the
command byte). The FSM enters S_CTRL and holds SIWU# low for the
duration of the command; the FT240X acts on the falling edge to flush
its TX FIFO to USB immediately rather than waiting for its 16 ms
latency timer. Useful for snappy interactive response (single-keystroke
echoes) without globally lowering the FT240X latency timer on the host
side.

**Activity LEDs.** All three LEDs are combinational decodes of existing
FSM signals — zero added flops:
- `led_act` = `~state[S_IDLE]` (any transaction in progress)
- `led_tx`  = `drive_ft_d`    (we are driving the FT bus, i.e. writing
                              a byte out)
- `led_rx`  = `drive_amiga_d` (we are driving the Amiga bus, i.e.
                              presenting a byte in)

Visible during sustained traffic (typing, file transfers). Single
isolated bytes pass through too quickly (~10–50 µs) to be visible by
themselves; this is the same "lit while active" approach used in the
[SDBox-v2 AVR firmware fork](https://github.com/jbilander/amiga-par-to-spi-adapter/blob/master/avr/main.c)
where the LED is asserted together with the SPI chip-select for the
duration of a transaction.

**Milestone-1 scope.** Only READ1 and WRITE1 commands (counts 1–64) are
implemented. READ2/WRITE2 (long-form, >64 bytes) and the broader
control-command space (D7=1, D6=1) reach states that idle cleanly on
REQ release; only the SIWU# flush function of CTRL is wired in. Extend
these once basic byte flow is proven on hardware. Adding READ2/WRITE2
would need roughly +10 macrocells which **will not fit** the LC4064V at
the current utilization — that's a feature for an LC4128V (different
package, board respin) or an RP2350-based redesign.

## Building

You need **ispLEVER Classic 2.1** (Lattice's free legacy toolchain,
Windows-only). Open `isplever/Par2Ser.syn` in the Project Navigator,
then **Process → Fit Design**. The tool runs synthesis (LSE), fits,
and generates `par2ser.jed`.

The `Par2Ser.lci` constraint file in this repo carries:
- Pin assignments matching the Rev 2A schematic
- IO types (LVTTL for most, LVTTL_5V for the `rst_n` input, LVCMOS33_OD
  for the open-drain `amiga_ack_n` output)
- SLOW slew rate on all outputs
- Timing constraint: 83.33 ns clock period (12 MHz)

The `Par2Ser.lct` file is the tool's working copy and is regenerated on
load — it is not tracked in git.

## Programming the CPLD

The CPLD is programmed via JTAG using **ispVM System** (also part of the
free ispLEVER toolchain). A cheap FT4232H-Mini-Module can act as the
JTAG cable: with the FTDI driver bound to channel A (interface 0), ispVM
sees it as a generic FTDI cable and can scan/program the device.

The recommended bring-up sequence:

1. Power the board via USB-C. The PWR LED should light.
2. With ispVM connected, **Scan Board** — the LC4064V's IDCODE should
   appear in the chain.
3. **Add Device → par2ser.jed**, then **Program**. The chain status
   should update to "PASS".

## Simulation

The smoke testbench in `sim/par2ser_tb.v` exercises a WRITE1 single-byte
path: command 0x01, drives POUT, checks that a WR pulse appears on the
FT side and that BUSY behaves correctly through REQ assert/deassert.
Run with Icarus Verilog:

```sh
cd cpld
iverilog -g2005 -o sim_par2ser rtl/par2ser_top.v rtl/par2ser_fsm.v sim/par2ser_tb.v
vvp sim_par2ser
```

Expected output ends with `WR pulses observed: 1 (expected >= 1)` and
`BUSY after release: 1 (expected 1/z)`.

## Bring-up sequence (on real hardware — pending)

1. **Confirm the fit** (already done — 62/64 macrocells).
2. **Generate JEDEC** — Process → Fit produces `par2ser.jed` in the
   ispLEVER working directory.
3. **Hardware sanity:**
   a. Power the board (USB-C plugged in). PWR LED on. CPLD should
      enumerate via JTAG (scan in ispVM returns the LC4064V IDCODE).
      The FT240X should enumerate as a VCP COM port (assuming CBUS5
      is configured for CLK12MHz — see top-level README).
   b. With the board on the Amiga parallel port and `par2ser.device`
      loaded, `set line par2ser.device` in kermit. The driver trace
      (KPrintF) should show open + SDCMD_QUERY succeeding as it did
      in Milestone 1.
   c. `connect` and type. The TX LED should light during keystrokes
      (Amiga → PC). On the PC side, the COM port should receive the
      bytes.
   d. Send bytes from the PC side. The RX LED should light and the
      bytes should arrive in `par2ser.device`'s ring buffer.

4. **What can fail and how to read it:**
   - PWR LED off: power section issue, not CPLD.
   - ispVM IDCODE scan fails: JTAG wiring or driver binding.
   - LEDs never light on Amiga traffic: FSM not entering DECODE,
     likely SELECT sync or pin assignment issue. Add a state-debug
     LED if needed (one of the 2 spare macrocells could be a
     `state[1]` decode out on pin 41).
   - TX works but RX doesn't: ACK/INTB_PORTS path. Check `drive_ack`
     in the FSM and that the driver has the rx_install code path
     enabled (`-DPAR2SER_HW`).
   - Garbled bytes: lane integrity (verify D0..D7 mapping
     end-to-end in the fitter report against the schematic netlist).

## What's deferred

- **READ2/WRITE2** for byte counts >64. Niklas's longer-transaction
  form; not needed for terminal-rate serial traffic, useful for bulk
  transfers. Won't fit the LC4064V at current utilization — needs an
  LC4128V (which doesn't exist in 48-TQFP, so a board respin) or an
  RP2350-based redesign.
- **Control command for FT240X status query.** Would let the driver
  poll exact FT240X FIFO state instead of just sensing /RXF. Could
  fit in the remaining 2 macrocells if found necessary.

## Conventions

- All registered logic is `always @(posedge clk)` with synchronous reset
  feeding into the IDLE state. The exception is the reset synchronizer
  itself, which has an async assert + sync deassert pattern.
- Tristate drivers use ternary `(oe ? value : 1'bz)` per-pin, gated by
  reset. The top-level explicitly forces high-Z during reset.
- No latches, no combinational feedback loops. The fitter produces a
  clean register-only synthesis (48 D flip-flops + a handful of T
  flip-flops the synthesizer picked for byte_count toggle bits).

## Lessons learned (so you don't repeat them)

Several things bit us during the long road to fitting this design.
Capturing them here in case they save someone else time:

- **On a near-full CPLD, the synthesizer's choice of flop type matters
  enormously.** Inferring `DFFRS` or `DFFSH` (flops with both async set
  and async clear) when the macrocell only supports one async path
  causes per-flop emulation that explodes macrocell count. Stick to
  single-async-path patterns (`always @(posedge clk or posedge X)`
  where there's only one X), or pure synchronous designs.
- **Internally-generated clocks are expensive.** If you do
  `reg div2; always @(posedge clk_in) div2 <= ~div2;` and then
  `always @(posedge div2)`, that `div2` becomes a clock net that
  consumes scarce CPLD clock-routing resources. On a tight design
  this can cost ~10 macrocells of cross-domain bridging structure.
  Stick to one (or few, pin-sourced) clock domains.
- **One-hot FSM encoding is often a CPLD win**, but only with the hold
  terms (`state[N] & ~exit_condition`) included for every waiting
  state. Omitting them gives a smaller fit *that doesn't work*.
- **The fitter results are sensitive to small perturbations in
  near-full designs.** Adding one signal can sometimes *reduce*
  macrocell count by nudging the placement search into a better
  basin. Adding a *correct, useful* signal that costs zero net cells
  isn't a paradox — it's the search landscape.

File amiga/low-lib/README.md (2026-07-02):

# Par2Ser low-lib (2E par-adapter transport)

Low-level wire transport for the Par2Ser parallel-port adapter. Derived from
Niklas Ekström's `spi-lib` (from amiga-par-to-spi-adapter), which spoke the
same 2E protocol to an SD-card SPI adapter. Renamed and trimmed for Par2Ser:

- `adapter.h` / `adapter.c` -- API + slow-path (250 kHz) transfer, port setup.
- `adapter_low.s` -- fast-path (8 MHz) block transfer (GNU as / m68k-amiga-elf).
- `misc_protos.h` -- inline stubs for Alloc/FreeMiscResource.

Removed from the original spi.c (not applicable to a UART bridge):
chip-select, card-present probing, and the CIA-A FLAG "card change" interrupt
(on Par2Ser the FLAG line is the FT240X RX doorbell, owned by par2ser.c).

The wire protocol and WRITE1/READ1 command encoding are unchanged from Niklas's
original and are decoded bit-for-bit by the Par2Ser CPLD FSM. Only WRITE1/READ1
(<= 64 bytes/command) are implemented on the current LC4064V; callers chunk at 64.

Original spi-lib (c) Niklas Ekström, April 2020 / July 2021.

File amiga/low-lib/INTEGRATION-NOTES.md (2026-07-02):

# Par2Ser low-lib — integration notes (task 1)

Wire-layer transport for `par2ser.device`, brought in from Niklas Ekström's
`spi-lib` and renamed/adapted for Par2Ser. This is the 2E par-adapter
protocol, NOT SPI (no chip-select, no SD card, no SPI peripheral).

## File map

| origin (Niklas / SDBox) | here |
| --- | --- |
| `spi.h` | `adapter.h` |
| `spi.c` | `adapter.c` |
| `spi_low.asm` (vasm) | `adapter_low.s` (GNU as) |
| `misc_protos.h` | `misc_protos.h` (rewritten) |
| `cia_protos.h` | removed (no FLAG vector here)|

Functions renamed so symbols match filenames: `adapter_{init,shutdown,
set_speed,read,write}`, `adapter_{read,write}_fast`.

## Substantive changes (not just renames)

1. **Assembly ported vasm → GNU as.** Niklas's upstream `spi_low.asm` is
   vasm/Devpac syntax (`;` comments, `XDEF`, `.`-local labels) and does NOT
   assemble under `m68k-amiga-elf-as`. `adapter_low.s` is GNU-as syntax and is
   verified to assemble (binutils m68k `as`, same family as your toolchain).

2. **SELECT-per-command framing chosen deliberately.** There are two upstream
   clocking models. Cross-checking against the Par2Ser CPLD FSM (par2ser_fsm.v
   + par2ser_top.v) shows the FSM requires:
     - `req_assert`  = SELECT (REQ) falling → S_IDLE → S_DECODE
     - `pout_edge`   = POUT (CLK) toggling  → clocks each byte
     - `req_deassert`= SELECT rising        → back to S_IDLE
     - `drive_busy`  = ~S_IDLE              → BUSY low while working
   That is the **card-present spi_low.asm** clocking (SELECT brackets each
   command, POUT clocks bytes). The **SDBox `common/spi-par-low.s`** clocking is
   different (SELECT held as an SD chip-select across a whole multi-byte
   command, everything clocked on POUT) and would leave the Par2Ser FSM stuck
   in S_IDLE — so it was NOT used. `adapter_low.s` follows the FSM-correct model.

3. **Disable()/Enable() bracketing adopted from SDBox production code.** Each
   transfer masks interrupts for its duration. This matters more on Par2Ser
   than on SDBox because RX is CIA-A FLAG interrupt driven — without masking, an
   `rx_server` FLAG could reenter the CIA lines mid-write. The fast path masks
   in `adapter_low.s` (`move.l 0x4,a6 / jsr Disable(a6)` … `Enable`, saving
   `d2/a5-a6`); the slow path masks in `adapter.c` (`Disable()`/`Enable()`).

4. **SD-card init removed.** `adapter_init()` drops `spi_get_card_present()`
   (its 0xc2 probe decodes as the FSM's is_ctrl/SIWU flush), the `AddICRVector`
   CIA-A FLAG install (that line is the RX doorbell owned by par2ser.c), and
   `spi_select`/`spi_deselect`. It only opens misc.resource, allocs the port +
   bits, and sets the CIA idle line state.

5. **VBCC `__reg(...)` → gcc `asm(...)`** on every register-pinned parameter,
   matching the house style already in `par2ser.c`. `misc_protos.h` prefers the
   NDK's `<proto/misc.h>` and only falls back to a gcc-syntax inline stub.

## Command encoding (verified against the FSM)

- WRITE1 `00xxxxxx`, length = size-1 in D5..D0  ↔ FSM `is_write`, `count_load`. ✓
- READ1  `01xxxxxx`                              ↔ FSM `is_read`.               ✓
- The >64 WRITE2/READ2 two-byte forms are NOT decoded by the current LC4064V
  (D7=1 routes to S_DRAIN). Callers chunk at 64 (transport.c). The asm keeps the
  >64 path for a future larger CPLD but it must not be reached today.

## Not compile-tested here (verify on your toolchain)

I have GNU `as` for m68k (so the ASSEMBLY is verified) but not
`m68k-amiga-elf-gcc` or your NDK 3.2 headers, so the C is not compile-tested:

1. **`asm("a0")` on declarations** — `par2ser.c` uses it on definitions; the
   pattern should carry. `make debug` will confirm.
2. **`<proto/misc.h>` availability** — if your NDK has it, the fallback stub in
   `misc_protos.h` is dead code. If not, verify the fallback LVOs (-6/-12).
3. **Register prefix in `adapter_low.s`** — written no-`%` (Motorola, the Amiga
   norm). If your `as` demands `%`, add `--register-prefix-optional` to ASFLAGS.

## Still open for task 2 (flagged, not blocking task 1)

`transport.c`'s `rx_data_pending()` reads CIA-A PRA bit 0 as the RX doorbell
(active-low), per the FSM's `drive_ack = S_IDLE & has_data` and top.v's
`amiga_ack_n` open-drain to CIA-A FLAG. **Confirm the exact bit + polarity on
`Par2Ser_rev2a_schematic.pdf`.** If ACK isn't readable as a CIA-A PRA bit,
`transport_poll_rx()` must be driven purely by the FLAG interrupt latch (one
unconditional READ1 per rx_server entry) instead of polled.

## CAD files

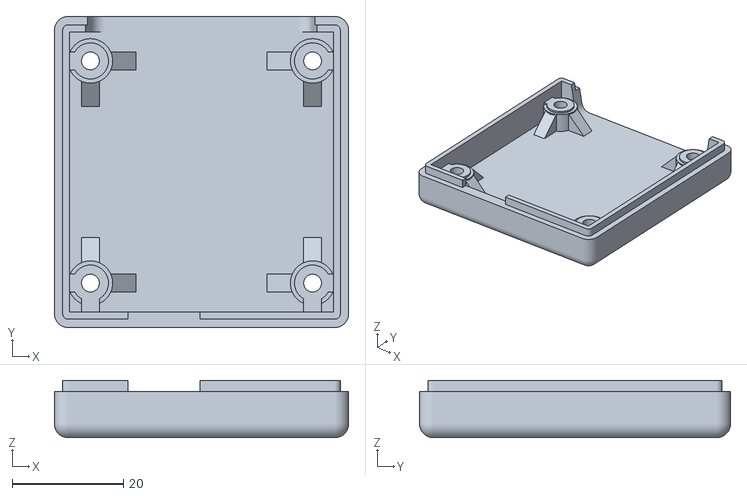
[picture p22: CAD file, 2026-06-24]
3D/Par2Ser_bottom.stl
53.0 x 56.0 x 10.3

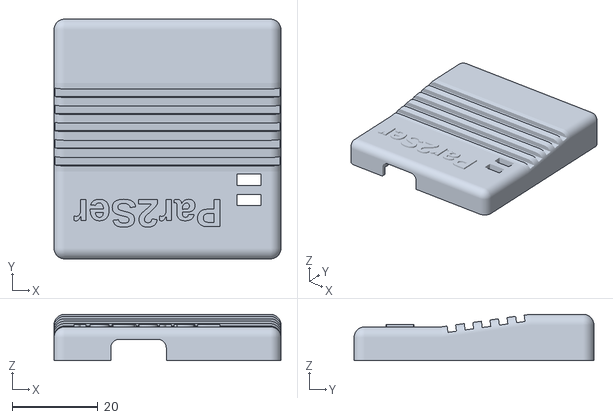
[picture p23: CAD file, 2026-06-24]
3D/Par2Ser_top.stl
53.0 x 56.0 x 10.8

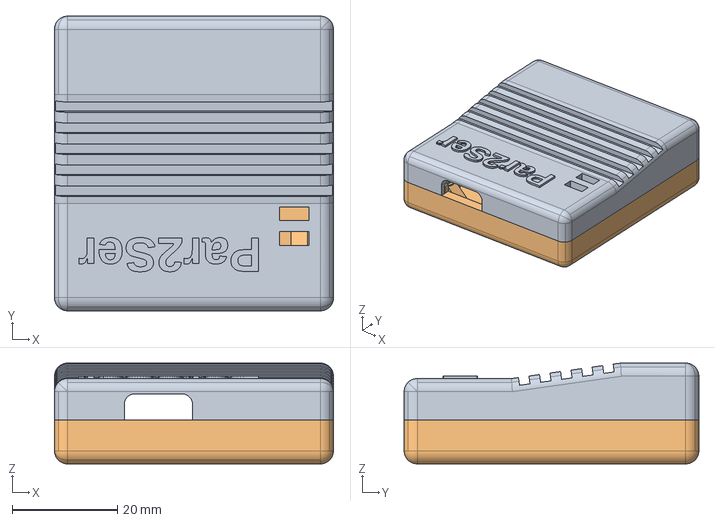
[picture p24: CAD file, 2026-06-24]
3D/Par2Ser.stp
53.0 x 56.0 x 19.2 mm

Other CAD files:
3D/Par2Ser_text.skp

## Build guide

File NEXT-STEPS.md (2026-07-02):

# NEXT-STEPS.md — Milestone 2 handoff

Working document for wiring `par2ser.device` to real hardware.
Complements the top-level `README.md` (which documents the completed
milestones — hardware bring-up and Milestone 1 driver skeleton) by
capturing open questions and the immediate next tasks.

## Where we are (as of this document)

**Hardware bring-up: complete.** The Par2Ser Rev 2A board is
programmed with `par2ser.jed` and validated end-to-end:

- FT240X MTP configured (CBUS5 → 12 MHz CPLD clock, VCP driver mode,
  descriptor strings), verified enumerating cleanly on macOS Catalina,
  Linux Mint, and Windows 8.1 SP2.
- LC4064V CPLD programmed via JTAG using an FT4232H-56Q Mini Module
  as generic FTDI cable through ispVM Classic 2.1, with
  TCK Low Pulse Width Delay = 3 to work around flywire signal
  integrity at the default 15 MHz TCK.
- A blink test design was flashed first to validate the toolchain
  (24-bit counter, alternating LEDs at ~0.7 Hz) — the LEDs blink
  correctly when the board is plugged into a USB host that
  enumerates the FT240X (needed for CBUS5 clock output).
- The real `par2ser.jed` is now programmed and the board sits in
  the FSM's S_IDLE state (all activity LEDs dark) when powered
  with no Amiga traffic.

**Milestone 1 (driver skeleton with stub transport): complete.**
`par2ser.device` was verified on a real Amiga 500 with KS 3.1.4 in
ROM + WB 3.1 booted from Gotek ADF:

- Driver loads and integrates with the OS (romtag/autoinit works).
- `cki196.exe` accepts `set line par2ser.device` — reports
  "Connecting thru par2ser.device, speed 9600" — and `connect` /
  escape work correctly.
- SDCMD_QUERY / SDCMD_SETPARAMS negotiation completes.
- With the stubbed `transport.c`, no bytes actually reach the
  FT240X (as designed for Milestone 1 — the point was to validate
  the driver architecture without hardware in the loop).

## What Milestone 2 is

Replace the stub transport with real hardware I/O so that bytes
typed in kermit on the Amiga arrive at `/dev/ttyUSB0` (or
`/dev/cu.usbserial-*` on macOS, or the COM port on Windows) on the
USB host — and vice versa.

The transport layer contract is defined in `amiga/transport.h`
(4 functions: `transport_init` / `_shutdown` / `_write` /
`_poll_rx`). The stub sketch in `amiga/transport.c` shows the
intended integration with Niklas Ekström's SPI library.

## Immediate next tasks

1. **Integrate Niklas's `spi.c`, `spi_low.asm`, and `spi.h`** from
   [github.com/niklasekstrom/amiga-par-to-spi-adapter](https://github.com/niklasekstrom/amiga-par-to-spi-adapter)
   into `amiga/`. Reference for how this was done in a sibling
   project: `jbilander/SDBox` uses the same protocol.

2. **Wire `transport.c` bodies to call `spi_initialize` /
   `spi_shutdown` / `spi_write`.** The transport.c stub already
   contains the sketch as a comment; it's a small mechanical change
   once the SPI library files are in place.

3. **Uncomment `-DPAR2SER_HW` and `spi.o` / `spi_low.o` in the
   Makefile** to compile in the real transport and the CIA-A FLAG
   receive interrupt server.

4. **Build, copy to A500, load par2ser.device, run kermit.** First
   test: send a single character from the Amiga and confirm it
   appears on the USB host terminal. This validates
   TX (Amiga → CPLD → FT240X → PC).

5. **Then RX**: type a character on the PC terminal, confirm it
   appears in kermit on the Amiga. This validates
   RX (PC → FT240X → CPLD → Amiga).

## Open questions to resolve during Milestone 2

Some of these are architectural questions that came up during
planning and were not fully resolved. Answering them requires
looking at the schematic, the CPLD Verilog (`cpld/par2ser_fsm.v`
and related), and Niklas's SPI code.

### Q1: Is `/RXF` wired to CIA-A FLAG on the Par2Ser board?

The FT240X's `/RXF` signal goes low when the RX FIFO has data
available (i.e., the PC has sent bytes that the Amiga hasn't read
yet). For the receive interrupt path to work efficiently, `/RXF`
needs to trigger a CPU interrupt.

Two possible routings on the Rev 2A hardware:

- **`/RXF` → CIA-A FLAG directly** (like SDBox does for its
  SD-card interrupt). This is what the driver's INTB_PORTS
  interrupt server expects: on every FT240X RX byte, the CPU
  wakes up, `rx_server()` runs, calls `transport_poll_rx()`,
  which issues a READ command via SPI protocol to drain the
  FIFO. **Efficient, event-driven.**

- **`/RXF` visible only to the CPLD.** In this case the CPLD
  would need to expose a status command (unused CPLD command
  slot exists in the FSM) that the Amiga could poll to check
  "is FT240X RX FIFO non-empty?" Requires either CPLD firmware
  changes (add the status command) or a polling loop with all
  its CPU overhead.

**Where to look:** `Par2Ser_rev2a_schematic.pdf` at the CIA-A FLAG
pin (parallel port pin 10 = ACK = CIA-A PA/FLAG) — trace
back to see what drives it. Also `cpld/par2ser_fsm.v` to see if
`/RXF` from the FT240X is a CPLD input pin and where it goes.

### Q2: Does the Par2Ser CPLD command encoding (D7/D6) match what `spi_low.asm` sends?

Both the SDBox and Par2Ser CPLDs use `D7`/`D6` as command bits and
`D5..D0` as data / partial-nibble. The Par2Ser FSM decodes:
- CTRL command (SIWU flush) when `D7=1, D6=1`
- WRITE command when a specific D7/D6 pattern is seen (need to
  verify exact encoding)
- READ command when another pattern is seen

If Niklas's spi_low.asm assumes the SDBox encoding (which was
originally an SD-card SPI adapter), and the Par2Ser CPLD FSM
decodes those bits with a different meaning, we'll get either
"nothing happens" or "wrong bytes on the FT240X TX FIFO."

**Where to look:** `cpld/par2ser_fsm.v` for the CPLD's D7/D6
decode logic. Compare to spi_low.asm's D7/D6 output patterns.
Also worth checking what the `par2ser.c` file header comment
means by "the D0-5/D6-7 split is invisible on the Amiga side" —
possibly Niklas's code just sends 8-bit payloads and D7/D6 are
the "command flavor" bits that spi_low knows to set for
READ vs WRITE.

### Q3: How does `transport_poll_rx()` return "one byte if available"?

Niklas's `spi_read(buf, count)` takes a known count and blocks
until that many bytes are read. But the driver's
`transport_poll_rx()` is a **peek-and-grab** primitive: "if a
byte is available return 1 and store it, else return 0 without
blocking."

Options:
- Check `/RXF` status first (via CIA FLAG state or CPLD status
  cmd) — if asserted, call `spi_read(out, 1)`; if not, return 0.
  Requires knowing how to read `/RXF` state cheaply.
- If the CPLD's READ command returns something in-band that
  means "no byte available" (e.g., a specific TDO pattern), we
  can call it unconditionally and interpret the result. Requires
  studying the FSM's READ command return value.

**This is what the transport.c stub's comment is honest about
being uncertain on.** Resolving this is the hardest part of the
Milestone 2 integration.

### Q4: Parallel-port resource acquisition

`par2ser.device` needs to grab the parallel port cleanly, so that
AmigaOS's built-in `parallel.device` or `PAR:` doesn't fight it.
The standard pattern is:

```
OpenResource("misc.resource")
AllocMiscResource(MR_PARALLELPORT, ...)
OpenResource("parallel.resource")
```

Niklas's `spi_initialize()` presumably does this — verify what
its return code contract is (`transport.c` sketch says
`spi_initialize(NULL) == 0` for success, need to confirm).

Also verify the port is released on `transport_shutdown()` so
other tools can use it after par2ser.device is closed.

## Testing plan for Milestone 2

Once the code is in place and building:

**Stage 0 — sanity check (no software yet):**
Power A500 with KS 3.1.4 in ROM, boot WB 3.1 from Gotek. Plug
Par2Ser into parallel port, USB-C into Linux Mint. Open
`sudo cat /dev/ttyUSB0` in a terminal. Observe: all Par2Ser
LEDs except PWR stay dark, no data on the terminal. If anything
appears (LEDs, garbage bytes), the CPLD FSM is decoding something
during boot that we need to understand before proceeding.

**Stage 1 — driver loads (already validated in Milestone 1):**
Skip re-testing; we already know this works.

**Stage 2 — TX path (first real test):**
Load par2ser.device, run cki196.exe, `set line par2ser.device`,
`connect`. Type a single character 'A'. Expected: TX LED on
Par2Ser briefly flashes; 'A' appears on the Linux terminal.

If nothing happens: check TX LED activity when typing (does the
CPLD FSM see the WRITE command?), check `/dev/ttyUSB0` is really
receiving nothing (not just terminal buffering).

**Stage 3 — RX path:**
Still in kermit `connect` mode, on the Linux side, type a character
into a terminal that has `/dev/ttyUSB0` open for write (e.g.,
`echo "B" > /dev/ttyUSB0`). Expected: RX LED on Par2Ser briefly
flashes; 'B' appears in kermit on the Amiga.

**Stage 4 — bidirectional / kermit protocol:**
Once both TX and RX work at the character level, try the full
kermit protocol: transfer a small file from Amiga to PC using
kermit on the PC side (using the FTDI VCP as the serial device
for kermit to talk to). This is the eventual end-user use case.

## KS 1.3 compatibility (deferred)

The current driver builds with the Bartman m68k-amiga-elf toolchain
using NDK 3.2 headers. The `gen_ks13_compat.py` script guards
against 2.0+ symbol usage at link time. c-Kermit (cki196.exe)
requires KS 3.1+ so KS 1.3 testing will need a different serial
client (NComm, Term, 1.3-era kermit port, etc.).

Recommended approach after Milestone 2 is working on KS 3.1.4:
1. Flash KS 1.3 to the Meggy ROM board.
2. Boot WB 1.3 from Gotek.
3. Try loading par2ser.device — likely to work given the compat guard.
4. Use NComm or similar as the serial client.
5. Document any 1.3-specific issues found.

## Reference / file inventory

Files in the Par2Ser repo that Milestone 2 will touch:

- `amiga/par2ser.c` — device driver main. Look for the
  `PAR2SER_HW` guard around `rx_install()`/`rx_remove()` calls.
- `amiga/transport.c` / `transport.h` — the stub that needs to
  be replaced with real SPI calls.
- `amiga/debug.c` — KPrintF via RawDoFmt + RawPutChar. Useful
  during Milestone 2 bring-up.
- `amiga/Makefile` — uncomment `-DPAR2SER_HW` and add `spi.o` /
  `spi_low.o` to OBJECTS when integration is ready.

Files to bring in from Niklas Ekström's repo
[amiga-par-to-spi-adapter](https://github.com/niklasekstrom/amiga-par-to-spi-adapter):

- `spi.h` — API declarations.
- `spi.c` — C wrapper around spi_low.
- `spi_low.asm` — assembly implementation of the 2E protocol on
  the CIA parallel port.

Files worth reading for context:

- `cpld/par2ser_fsm.v` — CPLD state machine. Answers Q1 and Q2.
- `cpld/README.md` — CPLD architecture rationale.
- `Par2Ser_rev2a_schematic.pdf` — for tracing `/RXF` routing and
  CIA-A FLAG connectivity.

## Bring-up gotchas to remember (from earlier sessions)

- **Power Par2Ser from a separate USB charger during JTAG
  programming**, not from the same PC running ispVM (otherwise
  the Par2Ser's FT240X appears as a competing "USB Serial
  Converter" that confuses ispVM). For running the device
  during Amiga testing, this doesn't matter — plug into any
  USB host that enumerates the FT240X, which is required for
  the CBUS5 12 MHz clock to run (chargers put FT240X into
  USB suspend with clocks off).
- **The TCK Low Pulse Width Delay = 3 setting is per-project
  in ispVM**, so it has to be re-set every time you switch
  between the blink and par2ser ispLEVER projects.
- **RN2 (10k pull-up for TMS) is optional for initial
  JTAG bring-up** — the FT4232H actively drives TMS and the
  LC4064V has an internal pull-up per IEEE 1149.1 — but should
  be populated before final use for noise immunity.

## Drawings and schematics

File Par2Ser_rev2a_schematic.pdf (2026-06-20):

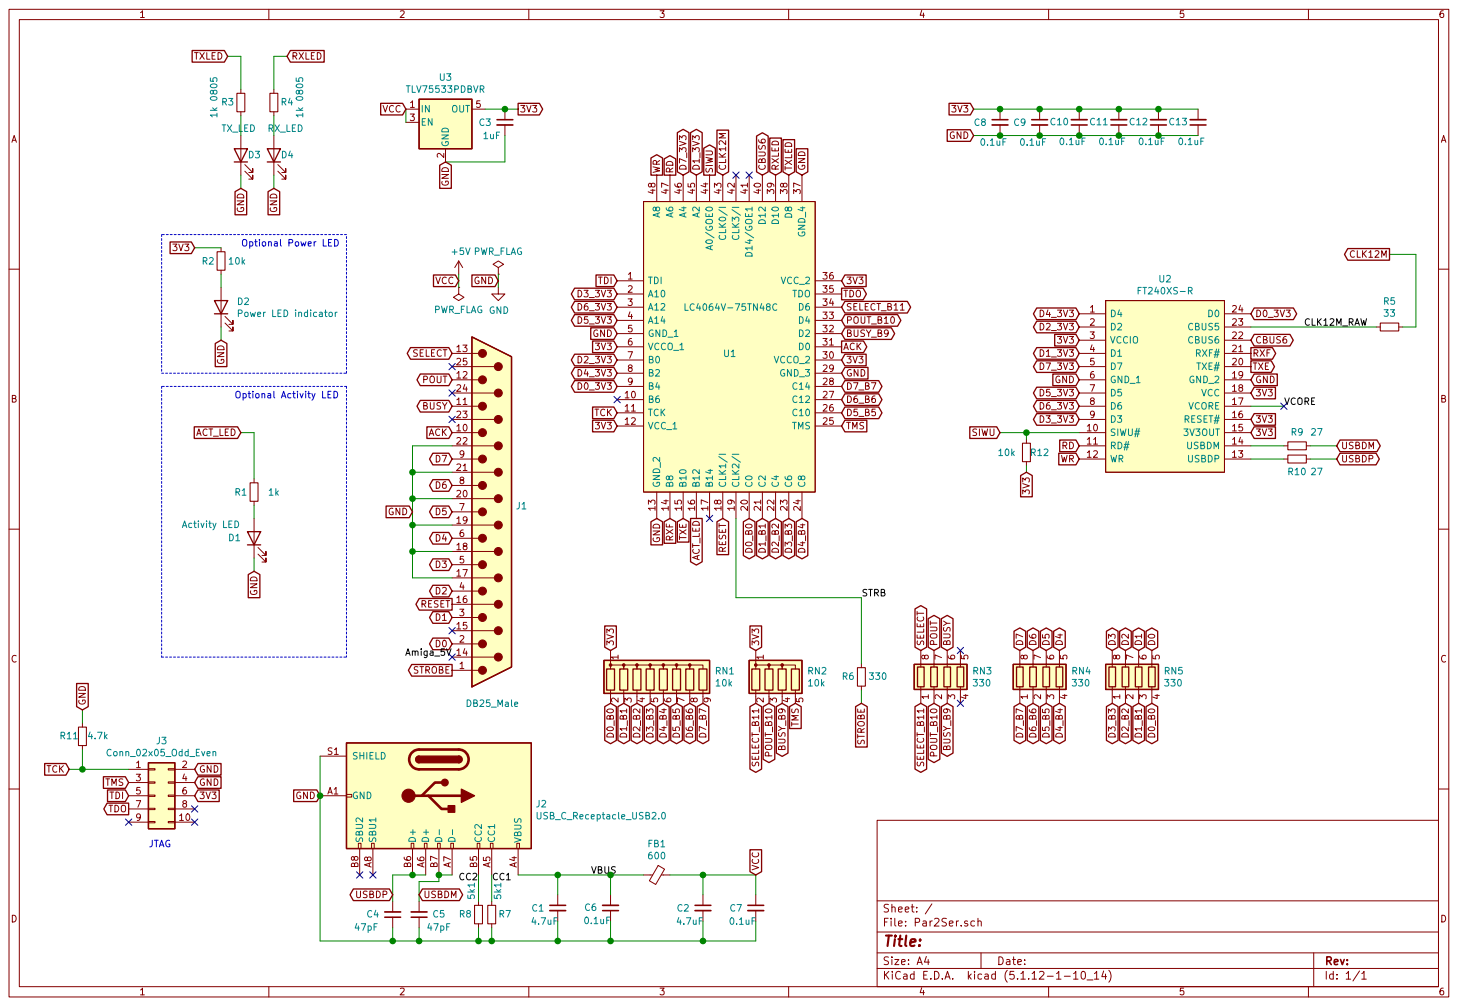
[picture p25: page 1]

Id: 1/1 Title: File: Par2Ser.sch Sheet: /

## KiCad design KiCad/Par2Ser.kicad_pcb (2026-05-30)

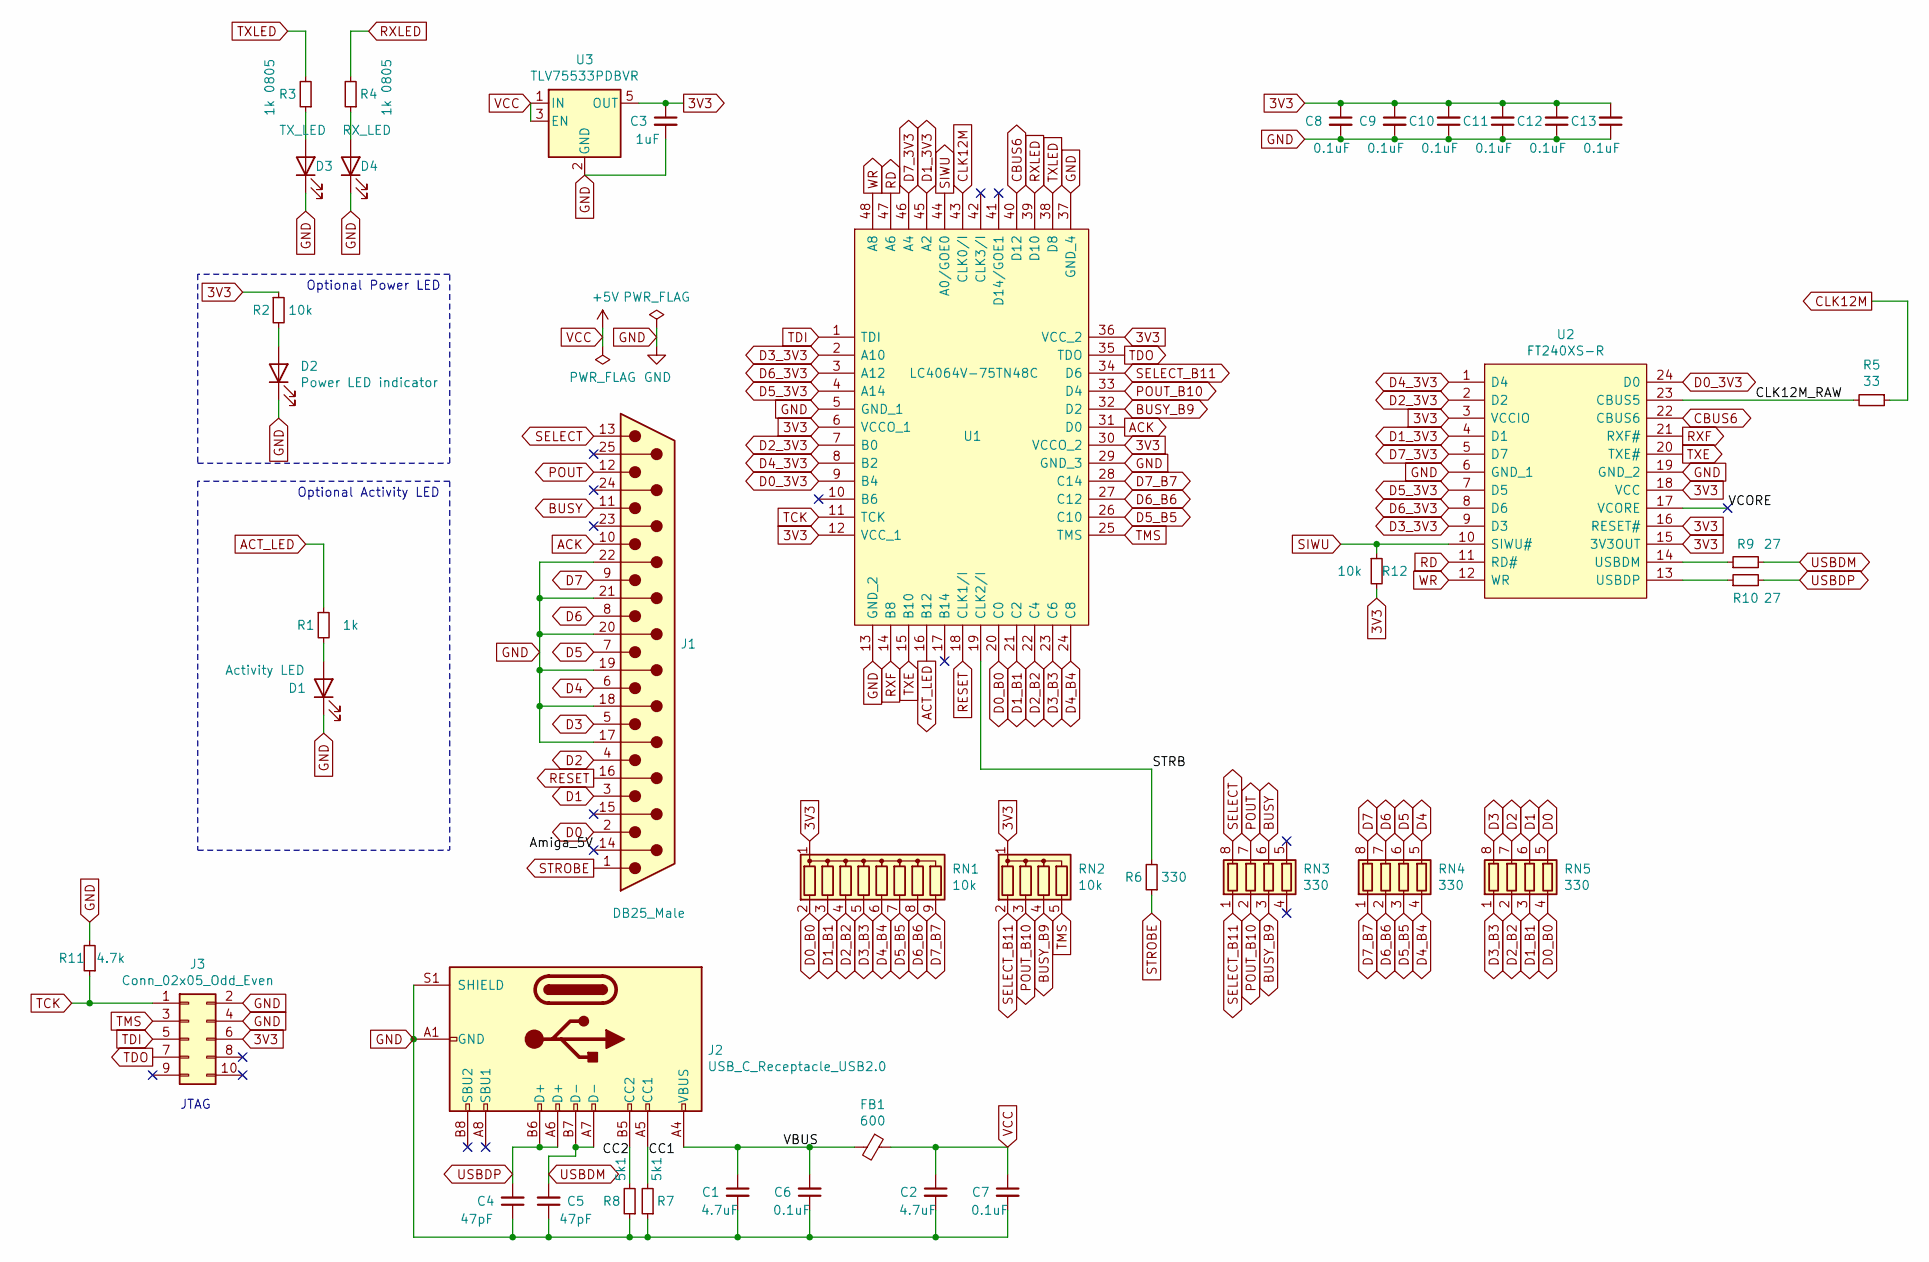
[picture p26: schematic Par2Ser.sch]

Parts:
C1, C2: 4.7uF; C_0805_2012Metric_Pad1.18x1.45mm_HandSolder
C3: 1uF; C_0805_2012Metric_Pad1.18x1.45mm_HandSolder
C4, C5: 47pF; C_0603_1608Metric_Pad1.08x0.95mm_HandSolder
C6, C7, C8: 0.1uF; C_0805_2012Metric_Pad1.18x1.45mm_HandSolder
C9, C10, C11, C12, C13: 0.1uF; C_0603_1608Metric_Pad1.08x0.95mm_HandSolder
D1: Activity LED; LED_Rectangular_W5.0mm_H2.0mm
D2: Power LED indicator; LED_Rectangular_W5.0mm_H2.0mm
D3: TX_LED; D_0603_1608Metric_Pad1.05x0.95mm_HandSolder
D4: RX_LED; D_0603_1608Metric_Pad1.05x0.95mm_HandSolder
FB1: 600; L_0805_2012Metric_Pad1.15x1.40mm_HandSolder
J1: DB25_Male; DSUB-25_Male_EdgeMount_P2.77mm
J2: USB_C_Receptacle_USB2.0; USB_C_Receptacle_HRO_TYPE-C-31-M-12
J3: Conn_02x05_Odd_Even; PinHeader_2x05_P2.54mm_Vertical
R1: 1k; R_0805_2012Metric_Pad1.20x1.40mm_HandSolder
R2: 10k; R_0805_2012Metric_Pad1.20x1.40mm_HandSolder
R3, R4: 1k 0805; R_0805_2012Metric_Pad1.20x1.40mm_HandSolder
R5: 33; R_0603_1608Metric_Pad0.98x0.95mm_HandSolder
R6: 330; R_0805_2012Metric_Pad1.20x1.40mm_HandSolder
R7, R8: 5k1; R_0805_2012Metric_Pad1.20x1.40mm_HandSolder
R9, R10: 27; R_0805_2012Metric_Pad1.20x1.40mm_HandSolder
R11: 4.7k; R_0805_2012Metric_Pad1.20x1.40mm_HandSolder
R12: 10k; R_0603_1608Metric_Pad0.98x0.95mm_HandSolder
RN1: 10k; R_Array_SIP9
RN2: 10k; R_Array_SIP5
RN3, RN4, RN5: 330; R_Array_Convex_4x0603
U1: LC4064V-75TN48C; TQFP-48_7x7mm_P0.5mm
U2: FT240XS-R; SSOP-24_3.9x8.7mm_P0.635mm
U3: TLV75533PDBVR; SOT-23-5

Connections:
3V3: C3.1, C8.1, C9.1, C10.2, C11.2, C12.2, C13.2, J3.6, R2.1, R12.2, RN1.1 (common), RN2.1 (common), U1.6 (VCCO_1), U1.12 (VCC_1), U1.30 (VCCO_2), U1.36 (VCC_2), U2.3 (VCCIO), U2.15 (3V3OUT), U2.16 (RESET#), U2.18 (VCC), U3.5 (OUT)
/Amiga_5V: J1.14
/CC1: J2.A5 (CC1), R7.2
/CC2: J2.B5 (CC2), R8.2
/CLK12M_RAW: R5.2, U2.23 (CBUS5)
/STRB: R6.2, U1.19 (CLK2/I)
/VBUS: C1.1, C6.2, FB1.2, J2.A4 (VBUS), J2.A9 (VBUS), J2.B4 (VBUS), J2.B9 (VBUS)
/VCORE: U2.17 (VCORE)
ACK: J1.10, U1.31 (D0)
ACT_LED: R1.1, U1.16 (B12)
BUSY: J1.11, RN3.6 (R3.2)
BUSY_B9: RN2.4 (R3), RN3.3 (R3.1), U1.32 (D2)
CBUS6: U1.40 (D12), U2.22 (CBUS6)
CLK12M: R5.1, U1.43 (CLK0/I)
D0: J1.2, RN5.5 (R4.2)
D0_3V3: U1.9 (B4), U2.24 (D0)
D0_B0: RN1.2 (R1), RN5.4 (R4.1), U1.20 (C0)
D1: J1.3, RN5.6 (R3.2)
D1_3V3: U1.45 (A2), U2.4 (D1)
D1_B1: RN1.3 (R2), RN5.3 (R3.1), U1.21 (C2)
D2: J1.4, RN5.7 (R2.2)
D2_3V3: U1.7 (B0), U2.2 (D2)
D2_B2: RN1.4 (R3), RN5.2 (R2.1), U1.22 (C4)
D3: J1.5, RN5.8 (R1.2)
D3_3V3: U1.2 (A10), U2.9 (D3)
D3_B3: RN1.5 (R4), RN5.1 (R1.1), U1.23 (C6)
D4: J1.6, RN4.5 (R4.2)
D4_3V3: U1.8 (B2), U2.1 (D4)
D4_B4: RN1.6 (R5), RN4.4 (R4.1), U1.24 (C8)
D5: J1.7, RN4.6 (R3.2)
D5_3V3: U1.4 (A14), U2.7 (D5)
D5_B5: RN1.7 (R6), RN4.3 (R3.1), U1.26 (C10)
D6: J1.8, RN4.7 (R2.2)
D6_3V3: U1.3 (A12), U2.8 (D6)
D6_B6: RN1.8 (R7), RN4.2 (R2.1), U1.27 (C12)
D7: J1.9, RN4.8 (R1.2)
D7_3V3: U1.46 (A4), U2.5 (D7)
D7_B7: RN1.9 (R8), RN4.1 (R1.1), U1.28 (C14)
GND: C1.2, C2.2, C3.2, C4.1, C5.1, C6.1, C7.2, C8.2, C9.2, C10.1, C11.1, C12.1, C13.1, D1.1 (K), D2.1 (K), D3.1 (K), D4.1 (K), J1.17, J1.18, J1.19, J1.20, J1.21, J1.22, J2.A1 (GND), J2.A12 (GND), J2.B1 (GND), J2.B12 (GND), J2.S1 (SHIELD), J3.2, J3.4, R7.1, R8.1, R11.2, U1.5 (GND_1), U1.13 (GND_2), U1.29 (GND_3), U1.37 (GND_4), U2.6 (GND_1), U2.19 (GND_2), U3.2 (GND)
unnamed: D1.2 (A), R1.2
unnamed: D2.2 (A), R2.2
unnamed: D3.2 (A), R3.1
unnamed: D4.2 (A), R4.1
unnamed: R9.1, U2.14 (USBDM)
unnamed: R10.1, U2.13 (USBDP)
POUT: J1.12, RN3.7 (R2.2)
POUT_B10: RN2.3 (R2), RN3.2 (R2.1), U1.33 (D4)
RD: U1.47 (A6), U2.11 (RD#)
RESET: J1.16, U1.18 (CLK1/I)
RXF: U1.14 (B8), U2.21 (RXF#)
RXLED: R4.2, U1.39 (D10)
SELECT: J1.13, RN3.8 (R1.2)
SELECT_B11: RN2.2 (R1), RN3.1 (R1.1), U1.34 (D6)
SIWU: R12.1, U1.44 (A0/GOE0), U2.10 (SIWU#)
STROBE: J1.1, R6.1
TCK: J3.1, R11.1, U1.11 (TCK)
TDI: J3.5, U1.1 (TDI)
TDO: J3.7, U1.35 (TDO)
TMS: J3.3, RN2.5 (R4), U1.25 (TMS)
TXE: U1.15 (B10), U2.20 (TXE#)
TXLED: R3.2, U1.38 (D8)
USBDM: C5.2, J2.A7 (D-), J2.B7 (D-), R9.2
USBDP: C4.2, J2.A6 (D+), J2.B6 (D+), R10.2
VCC: C2.1, C7.1, FB1.1, U3.1 (IN), U3.3 (EN)
WR: U1.48 (A8), U2.12 (WR)

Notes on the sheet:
Optional Activity LED
Optional Power LED
JTAG

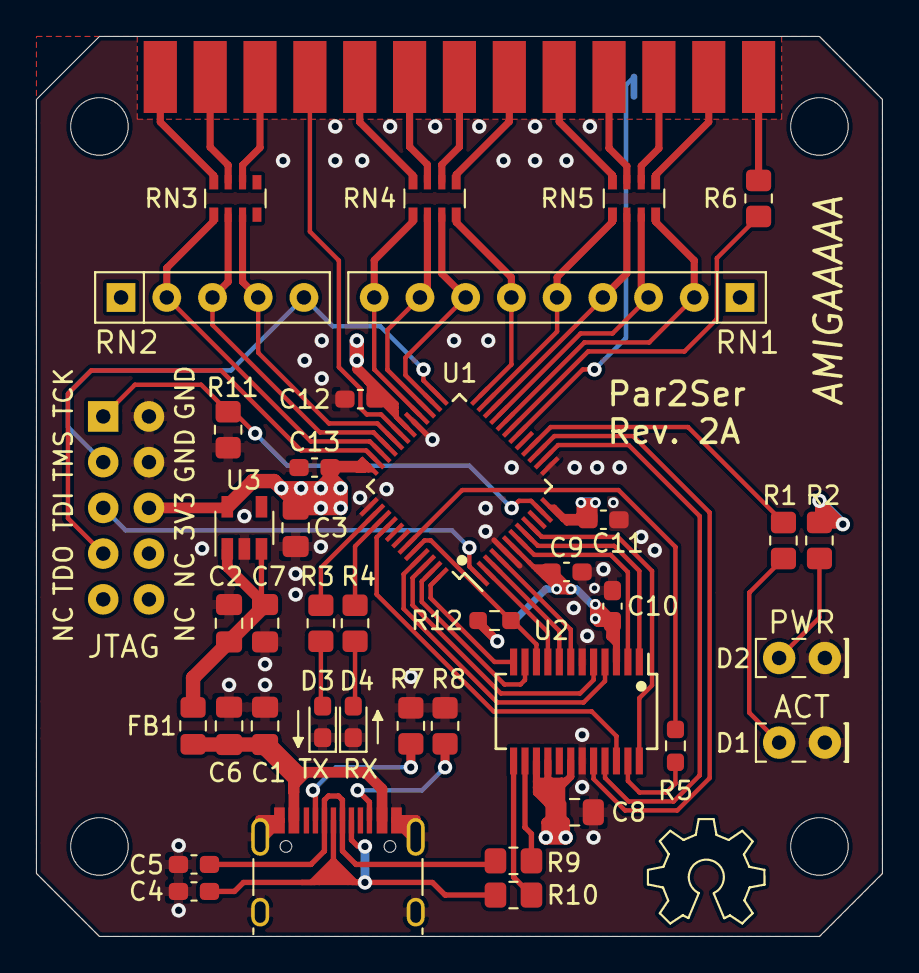
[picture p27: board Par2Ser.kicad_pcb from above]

Board: 4 copper layers, 47.0 x 50.0 mm, 41 parts (0 on the bottom side), 63 nets.

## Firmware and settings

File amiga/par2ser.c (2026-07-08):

/*
 * par2ser.device -- serial.device-compatible bridge over the Amiga parallel
 *                   port (Niklas Ekström's 2E parallel-adapter protocol -> FT240X).
 *
 * Structure follows jbilander/SimpleDevice (Bartman m68k-amiga-elf toolchain):
 *   - _start returns -1, inline-asm romtag, RTF_AUTOINIT
 *   - plain-C do_* workers behind register-pinned asm entry points
 *   - KPrintF debug via debug.c (RawDoFmt + RawPutChar)
 *
 * Serial machinery ported from Iain Barclay's 8n1.device (43.5): a RAM receive
 * ring buffer fed by an interrupt, CMD_READ satisfied from that buffer with
 * serial byte-stream semantics (a read completes on whatever input is
 * available, not only when io_Length is filled), and SDCMD_QUERY answering
 * "bytes available" from a software counter. The streaming semantics live here
 * in RAM; the hardware only ever needs to say "byte ready".
 *
 * Without PAR2SER_HW the transport is stubbed (transport.c) so the driver can
 * be loaded and its command flow traced in WinUAE with no hardware. With
 * PAR2SER_HW it drives the real adapter: chunked WRITE1 commands for transmit,
 * and a CIA-A FLAG receive interrupt (cia.resource ICR vector, one byte per
 * FLAG) for receive. Bidirectional interactive traffic and kermit file
 * transfers both work on real Rev 2A hardware; throughput optimization is the
 * remaining work (see README).
 */

#include <proto/exec.h>
#include <exec/resident.h>
#include <exec/errors.h>
#include <exec/io.h>
#include <exec/memory.h>
#include <exec/lists.h>
#include <exec/interrupts.h>
#include <devices/serial.h>
#include <hardware/cia.h>
#include <hardware/intbits.h>
#include <libraries/dos.h>
#include <resources/cia.h>

#include "transport.h"
#ifdef PAR2SER_HW
#include "low-lib/cia_protos.h"
#endif

/* KS 1.3 compatibility guard -- MUST be last, after all system/NDK headers,
 * so their unconditional declarations are seen before the poison pragmas.
 * Any KS 2.0+ call below this point becomes a compile error. */
#include <ks13_compat.h>

#if DEBUG
extern void KPrintF(CONST_STRPTR fmt, ...);
#define DBG(...) KPrintF((CONST_STRPTR)__VA_ARGS__)
#else
#define DBG(...) do { } while (0)
#endif

#define STR(s) #s
#define XSTR(s) STR(s)

#define DEVICE_NAME      "par2ser.device"
#define DEVICE_DATE      "(22 May 2026)"
#define DEVICE_ID_STRING "par2ser " XSTR(DEVICE_VERSION) "." XSTR(DEVICE_REVISION) " " DEVICE_DATE
#define DEVICE_VERSION   1
#define DEVICE_REVISION  0
#define DEVICE_PRIORITY  0

/* Default receive buffer size if the client does not request one. */
#define DEFAULT_RBUF_LEN 4096

/* ------------------------------------------------------------------ *
 *  io_Status modem bits.  serial.device returns the raw (active-low)
 *  CIA-B PRA control lines here, so a 0 bit = signal ASSERTED.  We have
 *  no real CIA serial lines on the parallel port, so we SYNTHESIZE a
 *  "fully connected" line: CD/CTS/DSR asserted (= 0).
 *
 *  >>> CARRIER DEBUG KNOB <<<
 *  If kermit still reports NO CARRIER, the CD polarity is the first
 *  suspect -- flip ST_CARRIER_PRESENT below and rebuild.  The whole word
 *  is KPrintF'd in sdcmd_Query so you can see exactly what kermit reads.
 * ------------------------------------------------------------------ */
#define ST_DTR  (1 << CIAB_COMDTR)   /* bit 7 */
#define ST_RTS  (1 << CIAB_COMRTS)   /* bit 6 */
#define ST_CD   (1 << CIAB_COMCD)    /* bit 5 */
#define ST_CTS  (1 << CIAB_COMCTS)   /* bit 4 */
#define ST_DSR  (1 << CIAB_COMDSR)   /* bit 3 */

/* active-low: clear a bit to assert it. 0x00 = CD+CTS+DSR all asserted. */
#define ST_CARRIER_PRESENT  0

/* serial.device command numbers (devices/serial.h): SDCMD_QUERY=9,
 * SDCMD_BREAK=10, SDCMD_SETPARAMS=11, CMD_* per exec/io.h. */
#ifndef NSCMD_DEVICEQUERY
#define NSCMD_DEVICEQUERY 0x4000
#endif
#define NSDEVTYPE_SERIAL  11

struct NSDeviceQueryResult {
    ULONG  DevQueryFormat;
    ULONG  SizeAvailable;
    UWORD  DeviceType;
    UWORD  DeviceSubType;
    const UWORD *SupportedCommands;
};

/* Private io_Flags bits for our own queue bookkeeping. NDK's serial.h here
 * doesn't export IOSERF_* (they're device-internal and SDK-dependent), so we
 * use our own. Bit 0 is IOB_QUICK (exec); bits 4/5 are safely ours. */
#define P2S_QUEUED  (1 << 4)
#define P2S_ACTIVE  (1 << 5)

/* NewList isn't prototyped in this NDK; do it inline (avoids the dependency). */
static inline void init_list(struct List *l)
{
    l->lh_Head     = (struct Node *)&l->lh_Tail;
    l->lh_Tail     = NULL;
    l->lh_TailPred = (struct Node *)&l->lh_Head;
}

/* ------------------------------------------------------------------ */

struct ExecBase *SysBase;
BPTR saved_seg_list;
BOOL is_open;

/* ---- serial state (global; single unit, mirrors 8n1's i_* globals) ---- */
static UBYTE        *rbuf;          /* receive ring buffer base            */
static ULONG         rbuf_len;      /* its size                            */
static UBYTE        *rb_in;         /* ISR write pointer                   */
static UBYTE        *rb_out;        /* reader pointer                      */
static UBYTE        *rb_end;        /* one past end (for wrap)             */
static volatile LONG rb_count;      /* bytes currently buffered            */
static volatile UBYTE rx_overrun;   /* set if ring overflowed              */

#if DEBUG
/* Diagnostic counters (dumped from cmd_query, task context, so the FLAG
 * ISR stays fast -- per-byte KPrintF at 9600 baud would perturb the very
 * timing we are measuring). Track burst behavior for the kermit transfer
 * hunt: total bytes fed, times the ring overflowed, high-water ring fill,
 * and reads completed by the ISR. */
static volatile ULONG dbg_rx_bytes;
static volatile ULONG dbg_rx_overruns;
static volatile ULONG dbg_rb_hiwater;
static volatile ULONG dbg_reads_done;
#endif

static struct IOExtSer *active_read;/* the one read being filled by the ISR*/
static struct List   read_q;        /* further reads waiting their turn    */

static ULONG  cur_baud   = 9600;    /* cosmetic: FT240X has no real baud   */
static ULONG  rbuf_req   = DEFAULT_RBUF_LEN;
static UBYTE  ser_flags;

static const UWORD supported_cmds[] = {
    CMD_RESET, CMD_READ, CMD_WRITE, CMD_CLEAR, CMD_FLUSH,
    SDCMD_QUERY, SDCMD_BREAK, SDCMD_SETPARAMS, NSCMD_DEVICEQUERY, 0
};

#ifdef PAR2SER_HW
static struct Interrupt rx_int;     /* cia.resource FLAG ICR vector        */
static BOOL  rx_int_added;
#endif

/* ------------------------------------------------------------------ *
 *  romtag / boilerplate (identical pattern to SimpleDevice)
 * ------------------------------------------------------------------ */
int __attribute__((no_reorder)) _start(void) { return -1; }
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

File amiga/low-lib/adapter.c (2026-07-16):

/*
 * adapter.c -- low-level 2E par-adapter transport for Par2Ser.
 *
 * Derived from Niklas Ekström's spi.c (April 2020 / July 2021, card-present
 * variant). The byte-level transfer routines are his; the wire protocol and
 * the WRITE1/READ1 command encoding are decoded bit-for-bit by the Par2Ser
 * CPLD FSM (par2ser_fsm.v). See adapter_low.s for the framing cross-check.
 *
 * REMOVED vs. the original spi.c (not applicable to a UART bridge):
 *   - spi_select / spi_deselect        : no SPI chip-select on Par2Ser.
 *   - spi_get_card_present             : no SD card; the 0xc2 probe is decoded
 *                                        by the FSM as is_ctrl (SIWU flush).
 *   - the CIA-A FLAG (AddICRVector)     : on Par2Ser the FLAG line is the
 *     interrupt install                  FT240X RX doorbell, owned by
 *                                        par2ser.c (which installs its own
 *                                        FLAG ICR vector via cia.resource).
 *
 * INTERRUPT-CONTEXT CONTRACT: the slow transfer paths (adapter_read_slow /
 * adapter_write_slow) contain NO Disable()/Enable() masking. Masking is the
 * CALLER's job, and only task-context callers need it (transport_write does
 * it). The FLAG ICR receive handler calls adapter_read() from interrupt
 * context, where masking is unnecessary (task code cannot preempt) and
 * Enable() is actively fatal: exec does not run interrupt handlers under
 * Disable(), so a Disable()/Enable() pair inside a handler drops the SR
 * interrupt mask to 0 on Enable() while the level-2 interrupt is still
 * asserted -> immediate recursive re-entry -> stack overflow. (This crashed
 * the machine on first use of the FLAG handler.) The FAST asm paths in
 * adapter_low.s still mask internally and therefore MUST NOT be called from
 * interrupt context as-is; adapter_set_speed likewise masks and is
 * task-context only.
 *
 * adapter_init() only opens misc.resource, allocs the parallel port + bits,
 * and sets the CIA idle line state. adapter_shutdown() frees them again.
 * Neither touches any interrupt vector.
 */

#include <exec/types.h>
#include <exec/libraries.h>
#include <hardware/cia.h>
#include <resources/misc.h>

#include <proto/exec.h>
#include "misc_protos.h"

#include "adapter.h"

/* KS 1.3 compatibility guard -- MUST be last, after all system/NDK headers,
 * so their unconditional declarations are seen before the poison pragmas.
 * Any KS 2.0+ call below this point becomes a compile error. */
#include <ks13_compat.h>

#define REQ_BIT		CIAB_PRTRSEL
#define CLK_BIT		CIAB_PRTRPOUT
#define ACT_BIT		CIAB_PRTRBUSY

#define REQ_MASK	(1 << REQ_BIT)
#define CLK_MASK	(1 << CLK_BIT)
#define ACT_MASK	(1 << ACT_BIT)

/* Fast-path block transfer implemented in adapter_low.s: a0=buf, d0=size.
 * That register convention is crossed ONLY here, via explicit register
 * variables + inline jsr (the same proven mechanism as misc/cia_protos.h) --
 * NOT via asm() parameter annotations, which this gcc ignores on the caller
 * side (see adapter.h). The asm saves d2/a5-a6 itself and scratches d1/a1.
 * NOTE: the fast paths Disable()/Enable() internally, so they are
 * task-context only, and currently unused (current_speed stays SLOW). */
static inline void call_read_fast(UBYTE *buf, ULONG size)
{
	register UBYTE *b asm("a0") = buf;
	register ULONG  s asm("d0") = size;
	__asm__ __volatile__ (
		"jsr    adapter_read_fast"
		: "+r" (b), "+r" (s)
		:
		: "d1", "a1", "cc", "memory");
}

static inline void call_write_fast(const UBYTE *buf, ULONG size)
{
	register const UBYTE *b asm("a0") = buf;
	register ULONG        s asm("d0") = size;
	__asm__ __volatile__ (
		"jsr    adapter_write_fast"
		: "+r" (b), "+r" (s)
		:
		: "d1", "a1", "cc", "memory");
}

static volatile UBYTE *cia_a_prb  = (volatile UBYTE *)0xbfe101;
static volatile UBYTE *cia_a_ddrb = (volatile UBYTE *)0xbfe301;

static volatile UBYTE *cia_b_pra  = (volatile UBYTE *)0xbfd000;
static volatile UBYTE *cia_b_ddra = (volatile UBYTE *)0xbfd200;

static long current_speed = ADAPTER_SPEED_SLOW;

static const char adapter_lib_name[] = "par2ser-adapter";

static struct Library *miscbase;

/* Track which resources we grabbed so shutdown frees only those. */
static BOOL got_port;
static BOOL got_bits;

/* Wait (bounded) for the adapter to clear BUSY (ACT). Returns remaining
 * count (0 = timed out). Caller runs with interrupts disabled. */
static int wait_until_active(void)
{
	int count = 32;
	UBYTE ctrl = *cia_b_pra;
	while (count > 0 && (ctrl & ACT_MASK))
	{
		count--;
		ctrl = *cia_b_pra;
	}
	return count;
}

void adapter_set_speed(long speed)
{
	/* Speed-set is itself a control command: assert SELECT, wait BUSY. */
	Disable();
	*cia_a_prb = speed == ADAPTER_SPEED_FAST ? 0xc5 : 0xc4;

	UBYTE prev = *cia_b_pra;
	*cia_b_pra = prev & ~REQ_MASK;

	wait_until_active();

	*cia_b_pra = prev;
	Enable();

	current_speed = speed;
}

/* Inter-byte pacing for the slow (bit-bang) write path. Each iteration is one
 * CIA-register read (~1.4us E-clock cycle), so the delay is ~TX_BYTE_DELAY *
 * 1.4us. This is the ONLY flow control between consecutive bytes on the write
 * side -- the data loop toggles CLK per byte with no per-byte BUSY handshake,
 * so this delay must be long enough for the CPLD FSM to consume one byte
 * (WRITE_WAIT -> WRITE_LATCH -> WRITE_FT -> WRITE_WAIT) before the next POUT
 * edge, AND for the FT240X to accept the write.
 *
 * OPTIMIZATION KNOB: the original value (32 -> ~45us) came from Niklas's SD
 * card needing ~32us/byte at 250kHz SPI -- irrelevant here. The FSM per-byte
 * cycle is sub-microsecond at 12MHz and two CIA writes are already ~1.4us
 * apart, so this is almost certainly far larger than needed. Reduce and test
 * for dropped/corrupted bytes (kermit Error Count). If 0 works reliably the
 * delay can be removed entirely; if not, it finds the real margin. */
#ifndef TX_BYTE_DELAY
#define TX_BYTE_DELAY 4      /* was 32; sweep this down toward 0 */
#endif

static void wait_tx_byte(void)
{
	UBYTE tmp;
	for (int i = 0; i < TX_BYTE_DELAY; i++)
		tmp = *cia_b_pra;
	(void)tmp;
}

/* Inter-byte pacing for the slow READ path: gives the FT240X/CPLD time to
 * present a byte on the bus before the Amiga clocks and reads it. Kept at the
 * original value for now -- RX already runs faster than TX and in the current
 * driver this loop only ever runs with size==1 (one byte per FLAG), so it is
 * NOT the RX bottleneck. Left as a separate knob so TX tuning cannot perturb
 * the working receive path; revisit when RX burst-drain is implemented. */
#ifndef RX_BYTE_DELAY
#define RX_BYTE_DELAY 32
#endif

static void wait_rx_byte(void)
{
	UBYTE tmp;
	for (int i = 0; i < RX_BYTE_DELAY; i++)
		tmp = *cia_b_pra;
	(void)tmp;
}
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

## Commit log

2026-05-22 Add kicad files from old design
    [Par2Ser.kicad_pcb, Par2Ser.sch]
2026-05-22 Add par2ser.device serial driver (Amiga side, milestone 1)
    serial.device-compatible bridge over the parallel port using Niklas
    Ekström's 2E par-to-spi protocol toward an FT240X USB FIFO, so
    unmodified comms programs can `set line par2ser.device`.
    Built for the Bartman m68k-amiga-elf (gcc 15.1) toolchain in the style
    of jbilander/SimpleDevice: _start/romtag/RTF_AUTOINIT, register-pinned
    asm entry points over plain-C do_* workers, KPrintF tracing via debug.c.
    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
2026-05-22 Add 3D model of USB-C connector
2026-05-22 Add LC4032V-5TN48C CPLD and remove Arduino Nano
    [Par2Ser.kicad_pcb, Par2Ser.sch]
2026-05-23 Remove unused components and begin pin assigment on CPLD, place and route pull-up resistor networks and series resistor networks for parallel port signals
    [Par2Ser.kicad_pcb, Par2Ser.sch]
2026-05-25 Replace FT232RNL with FT240X and do some routing
    [Par2Ser.kicad_pcb, Par2Ser.sch]
2026-05-26 Fix placement and routing of caps and resistors
    [Par2Ser.kicad_pcb, Par2Ser.sch]
2026-05-26 Add resistors on the two USB data lines
    [Par2Ser.kicad_pcb, Par2Ser.sch]
2026-05-26 Add 0.6/0.3 mm via
2026-05-26 Move to four layers
    [Par2Ser.kicad_pcb]
2026-05-27 Add remaining caps on 3V3 pins for CPLD and route power traces
    [Par2Ser.kicad_pcb, Par2Ser.sch]
2026-05-27 Add JTAG header
    [Par2Ser.kicad_pcb, Par2Ser.sch]
2026-05-27 Add 4.7k pull-down resistor on TCK and route all JTAG traces
    [Par2Ser.kicad_pcb, Par2Ser.sch]
2026-05-27 Add 3.3V regulator (TLV75533PDBVR) in SOT-23-5 package and add a 1 uF 0805 decoupling near VOUT pin and complete 3V3 routing and stitching
    [Par2Ser.kicad_pcb, Par2Ser.sch]
2026-05-27 Silkscreen fixes and add more via stitching
    [Par2Ser.kicad_pcb]
2026-05-28 Update .gitignore to track *.lci files
2026-05-28 feat(cpld): add Verilog implementation of Par2Ser bridge for LC4064V
    Port Niklas Ekstrom's 2E parallel protocol to the ispMACH 4000 CPLD,
    bridging the Amiga parallel port to the FT240X USB FIFO. Milestone-1
    scope: READ1/WRITE1 commands, RX-ready interrupt to CIA-A /FLAG,
    reset-aware bus tristate, and TX/RX/ACT activity LEDs.
    Fits the LC4064V-5TN48C: 59 of 64 macrocells, 50 registers, 195 pterms.
    Timing closes with large margin (worst path 5.40ns vs 83.33ns budget at
    12 MHz, ~78ns slack).
    Note on device choice: the design exceeds the 32-macrocell LC4032V. The
    byte-buffering data path (two 8-bit registers) plus FSM and synchronizers
    is fundamentally ~50 macrocells, so the pin-compatible LC40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
2026-05-28 Add footprint
2026-05-28 Add 32 Hz MEMS oscillator (SIT1534AI-H4-DCC-00.032) on clk3 input (pin 42)
    [Par2Ser.kicad_pcb, Par2Ser.sch]
2026-05-28 Add decoupling cap and 3.3v supply to MEMS Oscillator
    [Par2Ser.kicad_pcb, Par2Ser.sch]
2026-05-28 chore(cpld): switch to LC4064V-75TN48C, add SiT1534 clk_slow input pin
    Switch device from the -5 speed grade to -75 in the ispLEVER project.
    Timing easily met at -75: the design's worst path at -5 was 5.40 ns
    against an 83.33 ns budget, so the ~1.5x slower -75 still has ~77 ns
    of slack. The -75 part is ~7 EUR and more widely stocked.
    Also accommodates the upcoming SiT1534 32 Hz MEMS oscillator added to
    the schematic for the LED stretcher: CBUS6 relocated to CPLD pin 40
    (B14, free I/O), and pin 42 (CLK3/I) is now available to receive the
    oscillator output. Verilog wiring for clk_slow lands in a follow-up
    commit along with the led_stretcher module.
2026-05-29 feat(cpld): one-hot FSM encoding, all three LEDs working
    Re-encode the transaction FSM from 4-bit binary to 9-bit one-hot.
    Every state == N test becomes a single wire instead of a 4-bit AND
    tree, which reduces product terms from 195 to 108 (-45%) and frees
    enough macrocells to fit all three LEDs while staying within the
    LC4064V's 64-macrocell budget.
    Behavior is preserved bit-for-bit from the previous binary FSM
    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
2026-05-29 Remove SIT1534 (Y1) slow clock not needed
    [Par2Ser.kicad_pcb, Par2Ser.sch]
2026-05-30 Change Ohm values on R1 (1k for Yellow ACT LED) and R2 (10k for Power indicator LED) tested and verified suitable levels of glow
    [Par2Ser.kicad_pcb, Par2Ser.sch]
2026-05-30 Cosmetic fix remove OSHW copper symbol leaving cog wheel area unfilled
    [Par2Ser.kicad_pcb]
2026-05-30 Add screenshot of device
2026-06-01 Update README.md
    Update readme with BOM for Rev. 2A
2026-06-15 feat(cpld): add SIWU# Send Immediate control on pin 44
    Add ft_siwu_n output driven by the FSM. SIWU# goes low whenever the
    FSM is in the S_CTRL state, which is entered when the Amiga issues a
    control command (D7=1, D6=1 in the command byte). This causes the
    FT240X to flush its TX buffer to USB immediately rather than waiting
    for the 16 ms latency timer.
    The S_CTRL state persists from when the command is recognized until
    the Amiga deasserts REQ; SIWU# stays low for that duration. The
    FT240X acts on the falling edge to trigger the flush, and holding
    it low for the remainder of the command is harmless.
    Synthesizes to a single product term:
    ft_siwu_n = !(rst_n_sync & state[S_CTRL])
    No new fl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
2026-06-15 Update .gitignore to track xml files
2026-06-15 docs: document FT240X validation across hosts and OSes
    Rewrite the "Programming the FT240X" section to reflect actual bring-up
    testing of the Rev 2A hardware. Adds a fast path using a supplied
    FT_PROG/Par2Ser.xml template, a manual walkthrough with screenshots,
    and a cross-OS driver-behavior table (macOS, Linux, Windows 10/11,
    Windows 8.1). Documents the Windows 8.1 quirk where a fresh host may
    bind only the bus-level driver on first plug-in, and the minimal
    "uninstall without deleting files, then replug" fix. Includes the
    12 MHz scope capture verifying CBUS5 clock output at R5.
2026-06-17 docs: add JTAG programming procedure with TCK delay fix
    Document the full JTAG bring-up procedure now that programming has been
    validated end-to-end with the FT4232H Mini Module as a generic FTDI cable.
    * Wiring table (AD0/AD1/AD2/AD3/GND → J3 pins 1/5/7/3/2|4) with
    photo of the actual hookup.
    * Note that RN2 (TMS pull-up) can be left unpopulated for initial
    bring-up since the FT4232H actively drives TMS and the LC4064V
    has an internal pull-up per IEEE 1149.1; still recommended to
    populate before final use.
    * Windows driver setup: the libusb-win32 → D2XX rebind via
    Device Manager → Update Driver Software → Let me pick from a list.
    * Power-from-USB-charger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
2026-06-17 docs: clarify only Interface 0 needs the D2XX driver rebind
    ispVM only uses channel A (Interface 0) of the FT4232H Mini Module
    for JTAG. Interfaces 1/2/3 can stay bound to whatever driver they
    had previously (typically Quad RS232-HS / libusb-win32) without
    affecting programming. Also document the required restart of
    ispLEVER/ispVM after the rebind for the new driver state to take
    effect.
2026-06-20 Add schematic pdf for rev2a
2026-06-20 Add spaceclaim source file for 3D printable case
2026-06-20 Git add STEP file top and bottom of case
    [Par2Ser.stp]
2026-06-20 Add Par2Ser 3D text sketchup file
    [Par2Ser_text.skp]
2026-06-20 Add 3D printable stl files
    [Par2Ser_bottom.stl, Par2Ser_top.stl]
2026-06-20 Add 3D-printable case section with CAD renders to README
2026-06-20 Fix shuffled image captions in 3D case section
2026-06-21 Document case assembly: LED fitting, finished unit, USB-C hole note
2026-06-24 Narrow USB-C cut-out for symmetric fit
    [Par2Ser.stp, Par2Ser_bottom.stl, Par2Ser_top.stl]
2026-07-01 docs: add NEXT-STEPS.md for Milestone 2 handoff
    Working document capturing project state at the transition from
    Milestone 1 (driver skeleton with stub transport, validated on real
    A500 with KS 3.1.4 + WB 3.1) to Milestone 2 (integrate Niklas
    Ekström's spi.c/spi_low.asm/spi.h and wire transport.c to real
    hardware I/O).
    Covers:
    * Current state summary (hardware bring-up complete, driver
    architecture validated with kermit's cki196.exe).
    * Concrete task list for the Milestone 2 integration.
    * Four open questions to resolve during Milestone 2:
    - Is /RXF wired to CIA-A FLAG or only visible to the CPLD?
    - Does the Par2Ser CPLD's D7/D6 command encoding match what
    spi_low.as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
2026-07-01 amiga: add low-lib adapter transport (Milestone 2, task 1)
    Bring Niklas Ekström's spi-lib into amiga/low-lib/ as the wire-layer
    transport, renamed to adapter.* since Par2Ser speaks the 2E par-adapter
    protocol, not SPI (no chip-select, no SD card, no SPI peripheral).
    spi.h -> adapter.h
    spi.c -> adapter.c
    spi_low.asm -> adapter_low.s
    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
2026-07-01 amiga: make Milestone 2 HW build compile and link with m68k-amiga-elf
    Fixes to get the -DPAR2SER_HW build through the Bartman m68k-amiga-elf
    toolchain (gcc + strict-prefix as). par2ser.device now builds and links
    with no unresolved symbols.
    low-lib/misc_protos.h:
    - Drop <proto/misc.h>: the NDK 3.2 version takes an implicit MiscBase
    (2-arg Alloc / 1-arg Free), but misc.resource is opened via
    OpenResource() so there is no auto-managed base. Hand-roll gcc-syntax
    inline stubs that pass the resource base explicitly in a6 (LVOs
    -6/-12), matching how adapter.c calls them.
    - Remove d0 from the FreeMiscResource clobber list; unitNum already
    occupies d0 as an input operand (gc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
    [adapter.c]
2026-07-01 low-lib: correct stale SPI-frequency wording in comments
    The slow/fast "250 kHz" / "8 MHz" labels came from Niklas's AVR code and
    referred to the SPI clock the adapter drove to the SD card. Par2Ser has no
    SPI bus (12 MHz CPLD, parallel byte-pipe), so those frequencies describe
    nothing here. Reword the adapter.h header comment, the adapter_set_speed
    prototype comment, and adapter.c's wait_40_us comment to describe the
    actual mechanism: SLOW = C bit-bang with a per-byte settling delay
    (~45 us, 32 E-clock-paced CIA reads), FAST = tight-loop asm with none.
    Comment-only; no behavior change.
    [adapter.c]
2026-07-02 amiga: fix debug formatting and gate RX for TX bring-up
    Two issues surfaced testing the -DPAR2SER_HW build on real hardware, both
    in the Amiga driver rather than the transport itself.
    debug.c: KPrintF passed a gcc va_list straight to RawDoFmt, but RawDoFmt
    takes a DataStream -- a pointer to the arguments as contiguous longwords,
    which it walks itself. A va_list aliased that closely enough for a single
    argument but derailed with multiple, so the first multi-arg debug line
    reached (SDCMD_SETPARAMS, 6 args) hung inside RawDoFmt. Marshal the varargs
    into a local contiguous ULONG[] via portable va_arg and pass that. All
    format specifiers in the codebase are %ld/%lx (verified), so each consumes
    o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
    [par2ser.c]
2026-07-02 cpld/fsm: fix FT240X write timing -- drive data across the WR pulse
    Typed bytes arrived at the PC as garbage although the Amiga driver reported
    wrote=1. Data-bus wiring verified 1:1 against the KiCad netlist and the
    ispLEVER constraint file, so the fault was WRITE-path timing in the FSM.
    Registered outputs skewed drive_ft_d one cycle late: ft_wr_pulse asserted
    (ft_wr high, FT240X latching on the following falling edge) while drive_ft_d
    was still 0, so the FT data bus was high-Z during the strobe and the chip
    latched a floating bus; drive_ft_d only came up on the falling-edge cycle
    itself, with no setup.
    Assert drive_ft_d across S_WRITE_LATCH | S_WRITE_FT so the bus is driven a
    full clock b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
2026-07-04 amiga: guard against KS 2.0+ calls with ks13_compat.h
    Include <ks13_compat.h> (from the NDK sys-include) as the last header in
    par2ser.c, transport.c, debug.c and low-lib/adapter.c. Its #pragma GCC
    poison directives turn any accidental KS 2.0+ (v34+) library call into a
    compile error, keeping par2ser.device loadable on Kickstart 1.3.
    Included after the NDK headers, whose version-agnostic declarations would
    otherwise trip the poison on declaration rather than use. Current sources
    are already 1.3-clean; this guards against regressions.
    [adapter.c, par2ser.c]
2026-07-04 README: reflect verified TX on Rev 2A hardware; rework Milestone 2
    Update the status banner from "untested / no board fabricated" to
    work-in-progress with transmit verified end-to-end on a real Rev 2A board;
    note receive is not working yet (RX gated off pending doorbell verification).
    Rewrite Milestone 2 to match what was actually built: split into Transmit
    (working) and Receive (next). Describe the real low-lib/adapter.* transport
    (renamed/reworked from Niklas's lib, vasm->GNU-as port, SD-card init removed)
    and the FT240X write-strobe timing fix in the FSM, replacing the old
    "add spi.c/spi_low.asm unchanged" plan. Add a note that the driver targets
    Kickstart 1.3 via ks13_compat.h.
2026-07-04 README: reword "2E par-to-spi protocol" to "2E parallel-adapter protocol"
    Par2Ser is a byte-pipe, not SPI -- avoid carrying the SPI association from
    the protocol's SD-card origin into the intro. Niklas's original
    amiga-par-to-spi-adapter remains credited by name in the Credits section.
2026-07-05 amiga: implement RX (cia.resource FLAG vector) and fix fatal ABI mismatch
    Bidirectional traffic now works on real Rev 2A hardware: characters typed
    on either machine arrive on the other.
    RX design: the adapter's ACK (open-drain, DB25 pin 10) connects only to
    CIA-A /FLAG -- an interrupt-only CIA input, confirmed against the KiCad
    netlist -- so there is no readable doorbell level; the FLAG interrupt
    itself is the data-available signal. Register on the FLAG ICR bit via
    cia.resource (AddICRVector) rather than an INTB_PORTS server: cia.resource
    dispatches only genuine FLAG events and owns the shared ICR correctly.
    The handler reads exactly ONE byte per FLAG; the CPLD's IDLE-gated ACK
    re-asserts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
    [adapter.c, par2ser.c]
2026-07-05 README: bidirectional link verified; document RX design and known issues
    Receive now works on real hardware -- update the banner and replace the
    "Receive -- next" section with the implemented design: cia.resource FLAG
    ICR vector, one byte per /FLAG with hardware-self-clocking drain via the
    CPLD's IDLE-gated ACK, and the open-time doorbell prime. Summarize the
    two deep bugs fixed on the way (gcc ignoring asm() register params on
    prototypes; the CPLD READ handshake rework). Add Known issues: kermit
    file transfers fail with retries (current target), LED pulses too short
    to see, and a codepage note for non-ASCII characters.
2026-07-07 amiga: complete CMD_READ on available data — file transfers work
    Kermit file transfers failed with "Too many retries" though RX was
    flawless (every packet's bytes arrived, zero overruns, ring count exact,
    but zero reads ever completed). Cause: read_copy() completed a CMD_READ
    only when io_Actual >= io_Length, but kermit posts reads with a large
    buffer (e.g. 9064) as a MAXIMUM, expecting whatever has arrived. Each
    28-byte packet copied in but the read stayed pending forever waiting to
    fill the buffer, so kermit timed out and retried every packet.
    Per the Amiga byte-stream convention (console.device: "if there is some
    input, but not as much as can fill io_Length, the request will be
    satisfi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
    [par2ser.c]
2026-07-08 amiga: fix -Wempty-body warning in release build
    The no-op DBG() macro expanded to nothing, so `if (cond) DBG(...);`
    became `if (cond) ;` -- an empty if body the compiler flags under
    -Wempty-body in release (non-DEBUG) builds. Expand the no-op DBG() to
    `do { } while (0)` in both par2ser.c and transport.c, the standard idiom
    for a statement-like macro that is always a valid (empty) statement.
    Release build is now warning-clean.
    [par2ser.c]
2026-07-16 README: file transfers work; document throughput status and next steps
    Update the banner from "transfers do not succeed" to proof-of-concept
    working: both directions verified on Rev 2A hardware, ~3400 CPS TX /
    ~1400 CPS RX (release), short of 8n1.device's 38400 baud (~3800 CPS) --
    so throughput is now the active work.
    Add the read-semantics bug and fix to the Receive section (kermit posts
    CMD_READ with a large buffer as a maximum; completing only when
    io_Actual >= io_Length hung every packet). Replace Known issues with a
    Throughput section: the CPS table, the DEBUG-build measurement trap
    (~570 CPS with thousands of retransmits vs ~3× that in release), the
    per-byte TX delay cut (45us -> 5.6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
2026-07-16 low-lib: cut the per-byte TX delay -- ~1900 -> ~3400 CPS
    adapter_write_slow() inherited a ~45us busy-wait per byte from Niklas's
    SD-card timing (~32us/byte at 250kHz SPI), which is irrelevant on
    Par2Ser: the CPLD FSM consumes a byte in well under a microsecond at
    12MHz, and two consecutive CIA writes are already ~1.4us apart on the
    E-clock. The delay is the only flow control between bytes on the write
    side (the data loop toggles CLK with no per-byte BUSY handshake), so it
    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

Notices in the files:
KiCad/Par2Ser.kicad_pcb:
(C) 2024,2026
